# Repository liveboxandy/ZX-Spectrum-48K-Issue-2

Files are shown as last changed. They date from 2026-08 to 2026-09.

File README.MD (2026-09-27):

This is a Kicad 10 project for an issue 2 16/48K ZX spectrum.

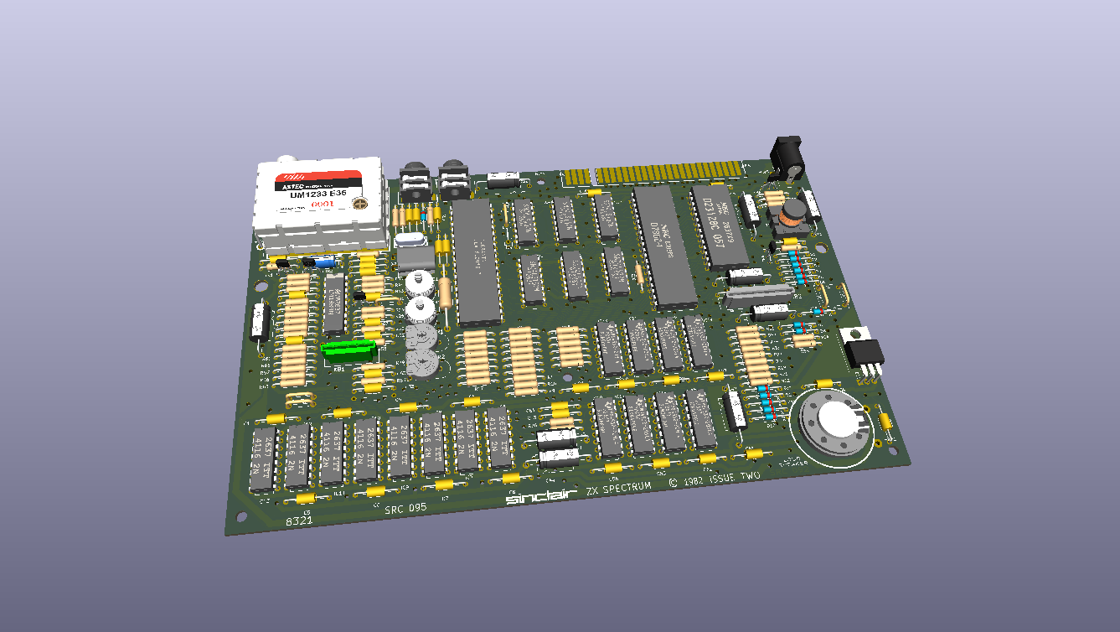
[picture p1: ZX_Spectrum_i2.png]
Assembled PCB


It was only done in order to produce an interactive bom (ibom.html) in the bom folder to aid in the debugging of faulty Speccies.

Although the gerbers appear to be correct to the original PCB I would not use them to get a PCB manufactured without a lot of checking.

It was created by overlaying pictures of a raw Issue 2 PCB, topside and bottomside and then creating the pcb layout from those and a readily available schematic.

Where there are differences the pictures took priority for routing and connections.

Where possible the Sinclair routing has been followed, including all the ground planes. 

Various mods have been released and the following have been applied to the pcb and schematic layout,

D14 replaced by C67 (100pF)                                         - Machine Code fix

R24 changed from 3K3 to (1K)                                        - Machine Code fix

R27 changed from 680R to (470R)                                     - Machine Code fix

R73 added between IC1/32 and +5V (1K)				    - Machine Code fix

C51 in layout between NMI and GND is not fitted, value unknown      - Not fitted

R60 changed from 100R to (270R)                                     - PSU Fix

R48 changed from 4K7 to (2K2)                                       - Colour quality

R49 changed from 18K to (8K2)                                       - Colour quality

R50 changed from 8K2 to (4K7)                                       - Colour Quality

R72 changed from 18K/47K to (10K)                                   - Colour quality

C65 changed from 100uF to (22uF) and positive identified correctly. - Colour quality

The following components do not have positions on the PCB and have to be fitted across other components,

TR6 ZTX313 added to schematic, but not in PCB layout. Base-IC2/30(A0), Collector-IC2/11(+5V), Emitter-IC1/33(IOREQ)

C74 47uF added to schematic but not in PCB layout. +ve TR5E/C34+, -ve TR5B(R58Left) - PSU Fix

ULA 5C112 requires the following,

R47 220R

R49 8K2

R56 220R

R63 220R

ULA 6C001 requires the following

R47 1K

R49 10K

R56 470R

R63 470R

According to the Service Guides, IC25/26 74LS157 should NOT be of NatSemi make.

Updated PCB length & Width along with hole positions. I still wouldn't get a PCB made from these gerbers.
Also included stp files in the /STP folder along with a 3D model of a fully asembled PCB.

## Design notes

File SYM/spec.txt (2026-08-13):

(kicad_symbol_lib
	(generator "kicad_symbol_editor")
	(symbol "23C128"
		(symbol "23C128_1_1"
	(symbol "4116"
		(symbol "4116_1_1"
	(symbol "4532"
		(symbol "4532_1_1"
	(symbol "74LS157"
		(symbol "74LS157_1_0"
		(symbol "74LS157_1_1"
	(symbol "74LS157-IC25-IC26"
		(symbol "74LS157-IC25-IC26_1_0"
		(symbol "74LS157-IC25-IC26_1_1"
	(symbol "BFC280831409"
		(symbol "BFC280831409_1_1"
	(symbol "CONFIG"
		(symbol "CONFIG_0_1"
		(symbol "CONFIG_1_1"
	(symbol "LM1889"
		(symbol "LM1889_1_1"
	(symbol "MODULATOR"
		(symbol "MODULATOR_0_1"
		(symbol "MODULATOR_1_1"
	(symbol "RAM_TYPE"
		(symbol "RAM_TYPE_1_1"
	(symbol "ULA"
		(symbol "ULA_1_1"
	(symbol "Z80CPU"
		(symbol "Z80CPU_0_1"
		(symbol "Z80CPU_1_1"

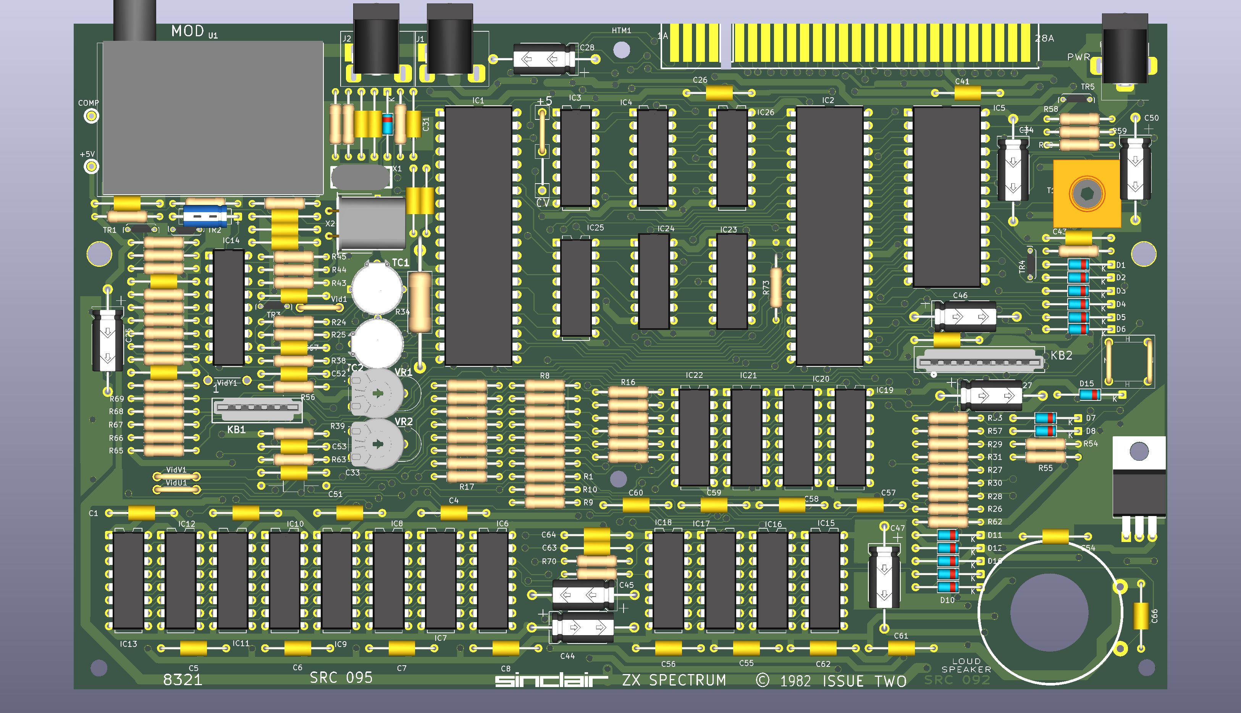
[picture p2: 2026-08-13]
ZX_Spectrum_i2-populated.png

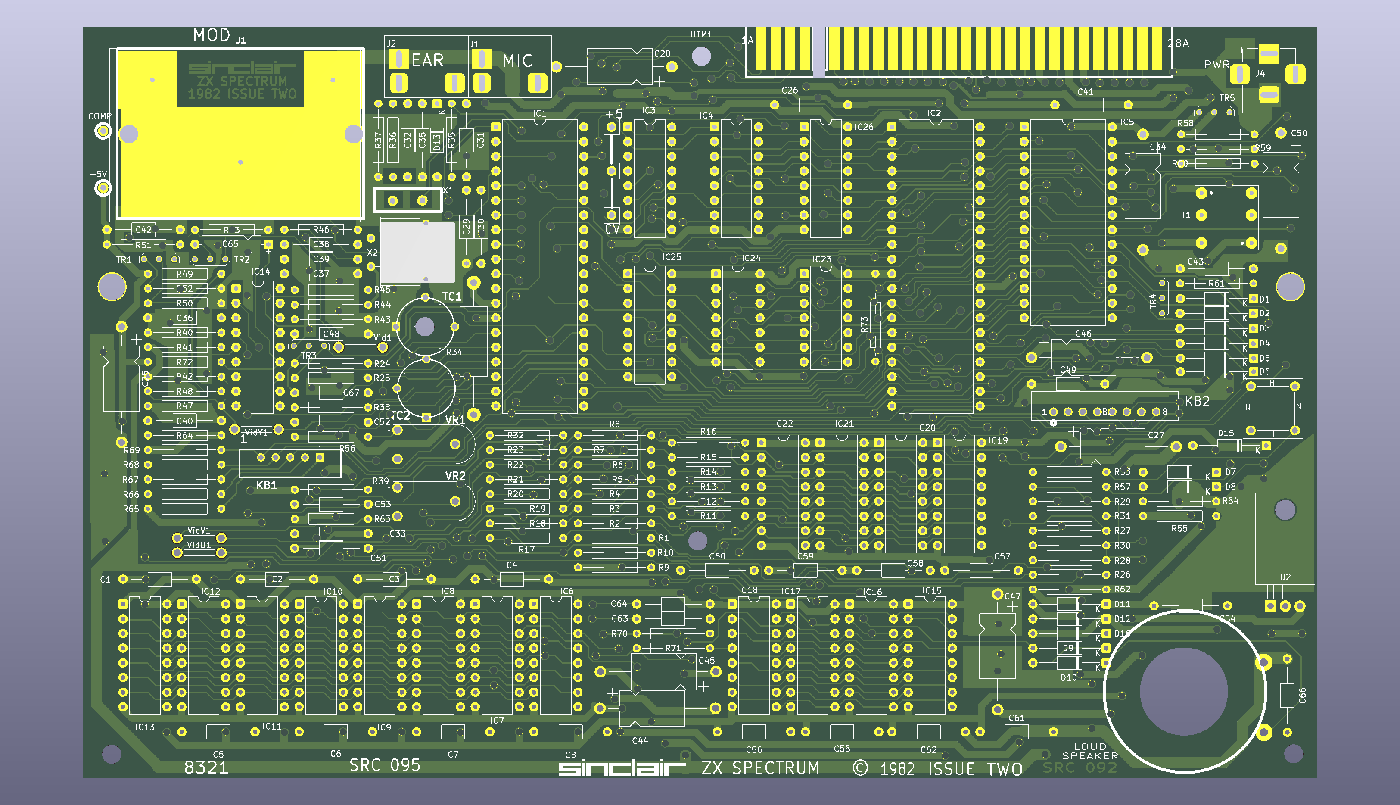
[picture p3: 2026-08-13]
ZX_Spectrum_i2-nonpopulated.png

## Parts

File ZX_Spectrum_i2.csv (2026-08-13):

Source: | E:\Kicad\ZX Spectrum Issue2\ZX_Spectrum_i2.kicad_sch
Date: | 2026-08-13T17:03:00
Tool: | Eeschema 10.0.4
Generator: | C:\Program Files\KiCad\7.0\bin\scripting\plugins/bom_csv_grouped_by_value_with_fp.py
Component Count: | 193
Ref | Qnty | Value | Cmp name | Footprint | Description | Vendor | DNP
C1, C2, C3, C4, C5, C6, C7, C8, C26, C29, C30, C33, C36, C40, C41, C42, C48, C49, C55, C56, C57, C58, C59, C60, C61, C62, C66 | 27 | 47nF | C_Small | MOD:C_Axial_L7.8mm_D2.4mm_P12.70mm_Horizontal | Unpolarized capacitor, small symbol
C25, C28, C47, C50 | 4 | 22uF | C_Polarized_Small | MOD:CP_Axial_L15.6mm_D6.0mm_P20.00mm_Horizontal | Polarized capacitor, small symbol
C27 | 1 | 1uF | C_Polarized_Small | MOD:CP_Axial_L15.6mm_D6.0mm_P20.00mm_Horizontal | Polarized capacitor, small symbol
C31, C32, C43 | 3 | 100nF | C_Small | MOD:C_Axial_L7.8mm_D2.4mm_P12.70mm_Horizontal | Unpolarized capacitor, small symbol
C34 | 1 | 22uF | C_Polarized_Small | MOD:CP_Axial_L11.0mm_D6.0mm_P20.32mm_Horizontal | Polarized capacitor, small symbol
C35, C39 | 2 | 10nF | C_Small | MOD:C_Axial_L7.8mm_D2.4mm_P12.70mm_Horizontal | Unpolarized capacitor, small symbol
C37, C38 | 2 | 33pF | C_Small | MOD:C_Axial_L7.8mm_D2.4mm_P12.70mm_Horizontal | Unpolarized capacitor, small symbol
C44, C45 | 2 | 100uF | C_Polarized_Small | MOD:CP_Axial_L15.6mm_D6.0mm_P20.00mm_Horizontal | Polarized capacitor, small symbol
C46 | 1 | 1uF | C_Polarized_Small | MOD:CP_Axial_L11.0mm_D6.0mm_P20.32mm_Horizontal | Polarized capacitor, small symbol
C52, C53, C64, C67 | 4 | 100pF | C | MOD:C_Axial_L7.8mm_D2.4mm_P12.70mm_Horizontal | Unpolarized capacitor
C54 | 1 | 470pF | C_Small | MOD:C_Axial_L7.8mm_D2.4mm_P12.70mm_Horizontal | Unpolarized capacitor, small symbol
C63 | 1 | 47pF | C_Small | MOD:C_Axial_L7.8mm_D2.4mm_P12.70mm_Horizontal | Unpolarized capacitor, small symbol
C65 | 1 | 22uF | C_Polarized_Small | MOD:CP_Axial_L10.0mm_D2.8mm_P12.70mm_Horizontal | Polarized capacitor, small symbol
C74 | 1 | 47uF | C_Polarized_Small | MOD:CP_Axial_L11.0mm_D6.0mm_P20.32mm_Horizontal | Polarized capacitor, small symbol
D1, D2, D3, D4, D5, D6, D7, D8, D9, D10, D11, D12, D13 | 13 | 1n4148 | D_Small | Diode_THT:D_DO-35_SOD27_P12.70mm_Horizontal | Diode, small symbol
D15 | 1 | BA157 | D_Small | Diode_THT:D_DO-35_SOD27_P12.70mm_Horizontal | Diode, small symbol
D16 | 1 | 5V1 | D_Schottky_Small | Diode_THT:D_DO-35_SOD27_P12.70mm_Horizontal | Schottky diode, small symbol
IC1 | 1 | ULA | ULA | Package_DIP:DIP-40_W15.24mm
IC2 | 1 | Z80 | Z80CPU | Package_DIP:DIP-40_W15.24mm | 8-bit General Purpose Microprocessor, DIP-40
IC3, IC4, IC25, IC26 | 4 | 74LS157 | 74LS157-IC25-IC26 | Package_DIP:DIP-16_W7.62mm | Quad 2 to 1 line Multiplexer
IC5 | 1 | ROM | 23C128 | Package_DIP:DIP-28_W15.24mm | MASKED ROM 128KiBit
IC6, IC7, IC8, IC9, IC10, IC11, IC12, IC13 | 8 | 4116 | 4116 | Package_DIP:DIP-16_W7.62mm | DRAM 16Kbit
IC14 | 1 | LM1889 | LM1889 | Package_DIP:DIP-18_W7.62mm
IC15, IC16, IC17, IC18, IC19, IC20, IC21, IC22 | 8 | 4532 | 4532_1 | Package_DIP:DIP-16_W7.62mm | DRAM 16Kbit
IC23 | 1 | 74LS32 | 74LS32 | Package_DIP:DIP-14_W7.62mm | Quad 2-input OR
IC24 | 1 | 74LS00 | 74LS00 | Package_DIP:DIP-14_W7.62mm | quad 2-input NAND gate
J1 | 1 | MIC | MIC1 | MOD:3.5mm_socket
J2 | 1 | EAR | EAR1 | MOD:3.5mm_socket
J3 | 1 | EDGE CONNECTOR | ZX_48K_EDGE_A_TOP | MOD:ZX_BUS_A_TOP | ZX Spectrum 48K Edge Connector A Top
J4 | 1 | Barrel_Jack | Barrel_Jack_MountingPin | MOD:BarrelJack_Horizontal
KB1 | 1 | KB | 5-520315-5 | MOD:55203155 | 5 Position FFC, FPC Connector Contacts, Vertical - 1 Sided 0.100" (2.54mm) Through Hole
KB2 | 1 | KB | 5-520315-8 | MOD:CONN_5-520315-8_TYC
LNK1 | 1 | ~ | RAM_TYPE | MOD:WireLink2
LNK2 | 1 | ~ | CONFIG | MOD:ROM_WireLink
LS1 | 1 | Speaker | Speaker | MOD:Speaker | Speaker
R1, R2, R3, R4, R5, R6, R7, R8, R27 | 9 | 470R | R_Small | MOD:R_Axial_L7.8mm_D2.4mm_P12.7mm_Horizontal | Resistor, small symbol
R9, R10, R11, R12, R13, R14, R15, R16, R49 | 9 | 8K2 | R_Small | MOD:R_Axial_L7.8mm_D2.4mm_P12.7mm_Horizontal | Resistor, small symbol
R17, R18, R19, R20, R21, R22, R23, R32, R57 | 9 | 330R | R_Small | MOD:R_Axial_L7.8mm_D2.4mm_P12.7mm_Horizontal | Resistor, small symbol
R24 | 1 | 1K0 | R_Small | MOD:R_Axial_L7.8mm_D2.4mm_P12.7mm_Horizontal | Resistor, small symbol
R25 | 1 | 180R | R_Small | MOD:R_Axial_L7.8mm_D2.4mm_P12.7mm_Horizontal | Resistor, small symbol
R26, R33, R36 | 3 | 680R | R_Small | MOD:R_Axial_L7.8mm_D2.4mm_P12.7mm_Horizontal | Resistor, small symbol
R28, R35, R65, R66, R67, R68, R69, R72 | 8 | 10K | R_Small | MOD:R_Axial_L7.8mm_D2.4mm_P12.7mm_Horizontal | Resistor, small symbol
R29, R41 | 2 | 1K5 | R_Small | MOD:R_Axial_L7.8mm_D2.4mm_P12.7mm_Horizontal | Resistor, small symbol
R30, R37, R40, R42, R45, R46 | 6 | 1K | R_Small | MOD:R_Axial_L7.8mm_D2.4mm_P12.7mm_Horizontal | Resistor, small symbol
R31 | 1 | 220K | R_Small | MOD:R_Axial_L7.8mm_D2.4mm_P12.7mm_Horizontal | Resistor, small symbol
R34 | 1 | 15R | R_Small | MOD:R34-11.94-4.5-22.86 | Resistor, small symbol
R38, R39 | 2 | 3K3 | R_Small | MOD:R_Axial_L7.8mm_D2.4mm_P12.7mm_Horizontal | Resistor, small symbol
R43 | 1 | 3K 2% | R_Small | MOD:R_Axial_L7.8mm_D2.4mm_P12.7mm_Horizontal | Resistor, small symbol
R44 | 1 | 5K1 2% | R_Small | MOD:R_Axial_L7.8mm_D2.4mm_P12.7mm_Horizontal | Resistor, small symbol
R47, R56, R63, R70, R71 | 5 | 220R | R_Small | MOD:R_Axial_L7.8mm_D2.4mm_P12.7mm_Horizontal | Resistor, small symbol
R48, R51, R52 | 3 | 2K2 | R_Small | MOD:R_Axial_L7.8mm_D2.4mm_P12.7mm_Horizontal | Resistor, small symbol
R50 | 1 | 4K7 | R_Small | MOD:R_Axial_L7.8mm_D2.4mm_P12.7mm_Horizontal | Resistor, small symbol
R53 | 1 | 390R | R_Small | MOD:R_Axial_L7.8mm_D2.4mm_P12.7mm_Horizontal | Resistor, small symbol
R54 | 1 | 100K | R_Small | MOD:R_Axial_L7.8mm_D2.4mm_P12.7mm_Horizontal | Resistor, small symbol
R55 | 1 | 56R | R_Small | MOD:R_Axial_L7.8mm_D2.4mm_P12.7mm_Horizontal | Resistor, small symbol
R58 | 1 | 1K 2% | R_Small | MOD:R_Axial_L7.8mm_D2.4mm_P12.7mm_Horizontal | Resistor, small symbol
R59 | 1 | 1K8 2% | R_Small | MOD:R_Axial_L7.8mm_D2.4mm_P12.7mm_Horizontal | Resistor, small symbol
R60 | 1 | 270R | R_Small | MOD:R_Axial_L7.8mm_D2.4mm_P12.7mm_Horizontal | Resistor, small symbol
R61, R62, R64 | 3 | 15R | R_Small | MOD:R_Axial_L7.8mm_D2.4mm_P12.7mm_Horizontal | Resistor, small symbol
R73 | 1 | 1K0 | R_Small | MOD:R_Axial_L7.8mm_D2.4mm_P15.20mm_Horizontal | Resistor, small symbol
T1 | 1 | COIL 13/39 | Transformer_1P_1S | MOD:Choke | Transformer, single primary, single secondary
TC1, TC2 | 2 | NS | C_Trim_1 | MOD:TrimmerCap | Trimmable capacitor
TR1, TR2, TR3, TR6 | 4 | ZTX313 | ZTX313 | MOD:TO-92Flat
TR4 | 1 | ZTX650 | Q_NPN_CBE | MOD:TO-92Flat | NPN transistor, collector/base/emitter
TR5 | 1 | ZTX213 | ZTX213 | MOD:TO-92Flat
U1 | 1 | MODULATOR | MODULATOR | MOD:Modulator
U2 | 1 | L7805 | L7805 | Package_TO_SOT_THT:TO-220-3_Horizontal_TabDown | Positive 1.5A 35V Linear Regulator, Fixed Output 5V, TO-220/TO-263/TO-252
Vid1 | 1 | Conn_01x02 | WireLink_7.62mm | MOD:Wire_Link_7.62mm
VidU1 | 1 | Conn_01x02 | WireLink_7.62mm | MOD:Wire_Link_7.62mm
VidV1 | 1 | Conn_01x02 | WireLink_7.62mm | MOD:Wire_Link_7.62mm
VidY1 | 1 | Conn_01x02 | WireLink_7.62mm | MOD:Wire_Link_7.62mm
VR1, VR2 | 2 | 2K2 | R_Potentiometer_Small | MOD:409HS1K | Potentiometer
X1 | 1 | 14MHz | Crystal_Small | MOD:X1 | Two pin crystal, small symbol
X2 | 1 | 4.433619MHz | Crystal_GND3_Small | MOD:Crystal_HC18-U_Horizontal_1EP_style2 | Three pin crystal, GND on pin 3, small symbol

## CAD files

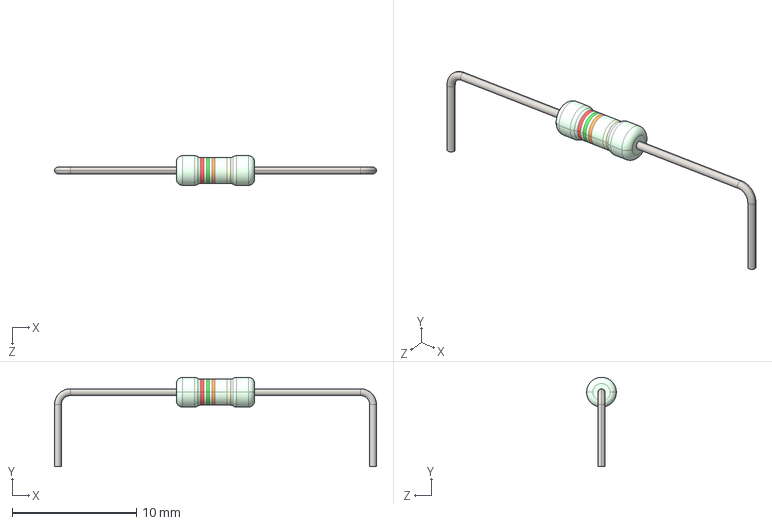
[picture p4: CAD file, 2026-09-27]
STP/Resistor-0207-6.3x2.4x25.40.STEP
26.0 x 7.20 x 2.40 mm

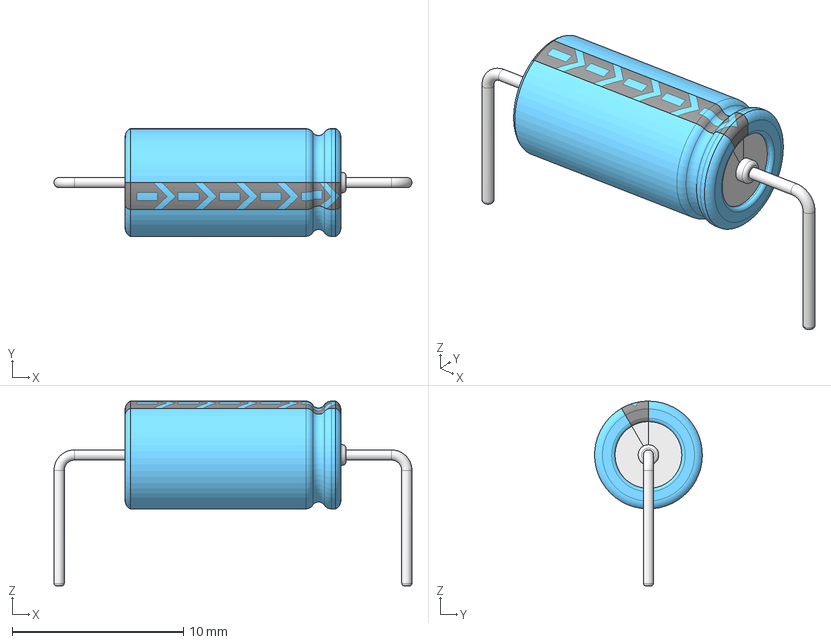
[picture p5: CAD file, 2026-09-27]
STP/Axial Capacitor.step
20.9 x 6.29 x 10.8 mm

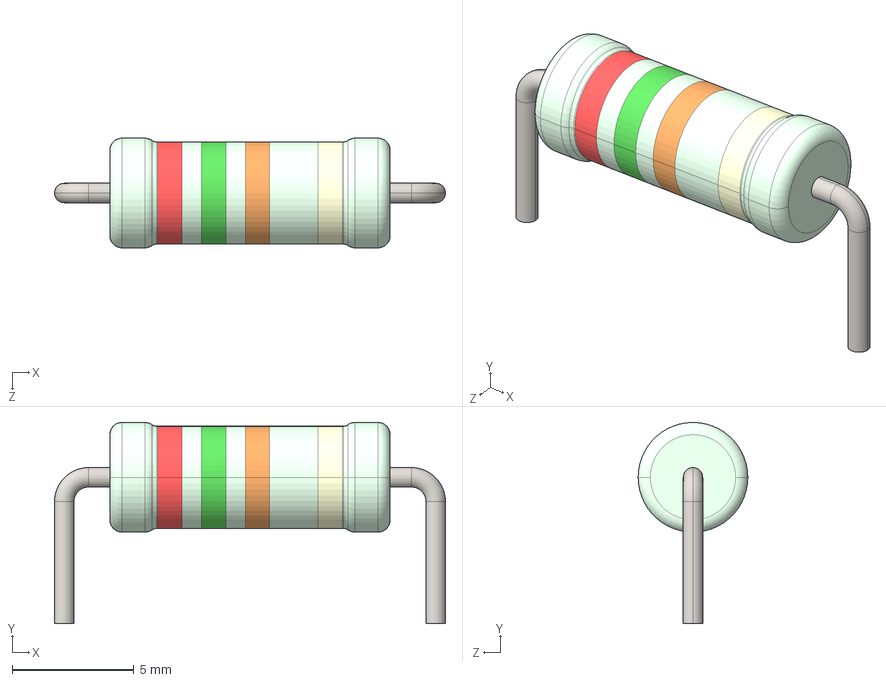
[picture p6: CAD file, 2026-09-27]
STP/Resistor-0414-11.5x4.5x15.24.STEP
16.0 x 8.25 x 4.50 mm

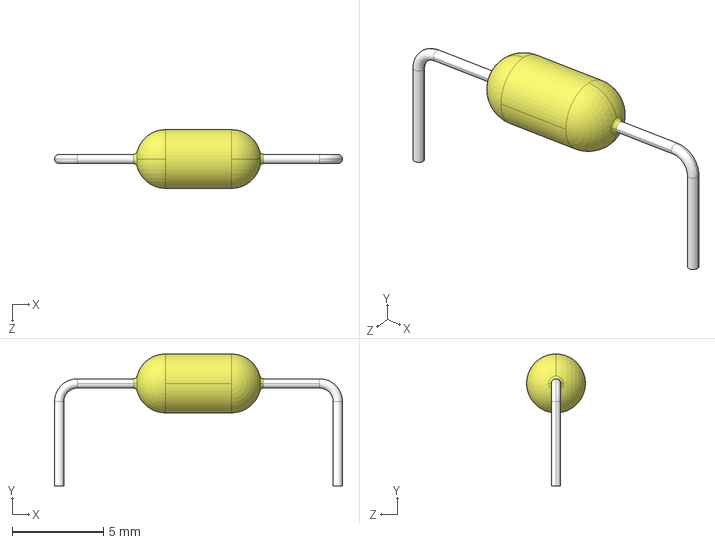
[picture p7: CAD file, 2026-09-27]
STP/Capacitor Ceramic No Polarity axial 15.24.STEP
15.8 x 7.22 x 3.22 mm

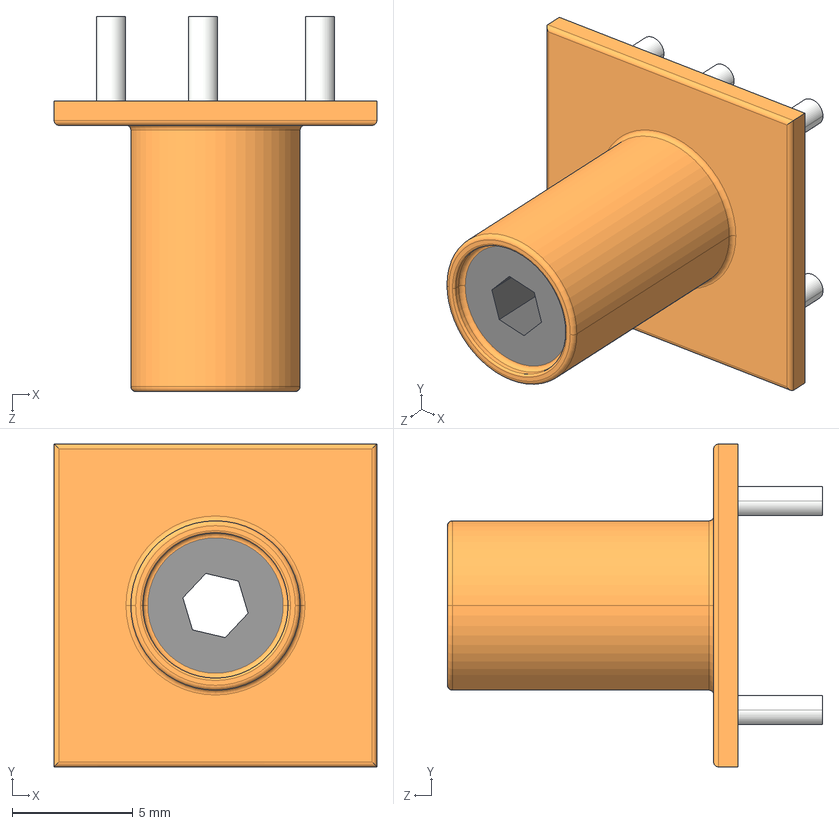
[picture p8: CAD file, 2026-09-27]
STP/13.34x13.34 Bobin.STEP
13.3 x 13.3 x 15.5 mm

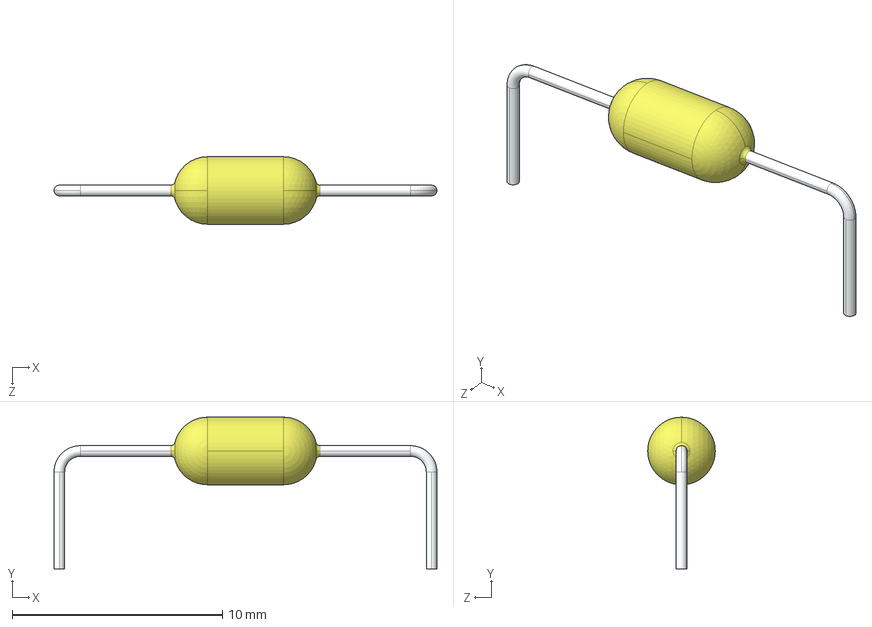
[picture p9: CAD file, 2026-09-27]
STP/Capacitor Ceramic No Polarity axial 17.72.STEP
18.2 x 7.22 x 3.22 mm

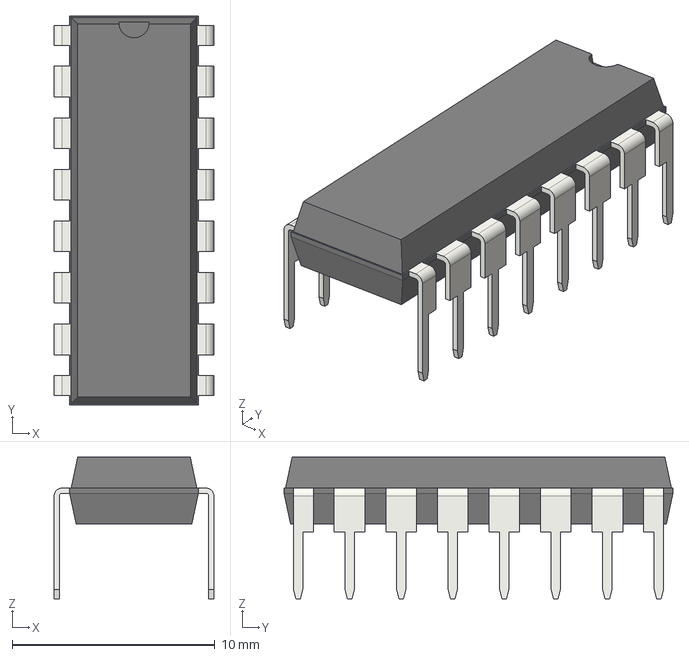
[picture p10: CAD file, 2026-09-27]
STP/DIP-16_W7.62mm.step
7.87 x 19.2 x 6.98 mm

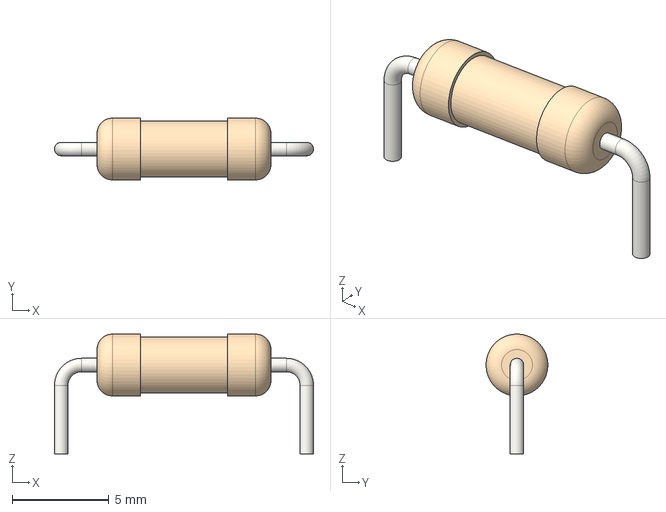
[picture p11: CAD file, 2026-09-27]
STP/R_Axial_DIN0309_L9.0mm_D3.2mm_P12.70mm_Horizontal.step
13.4 x 3.20 x 6.20 mm

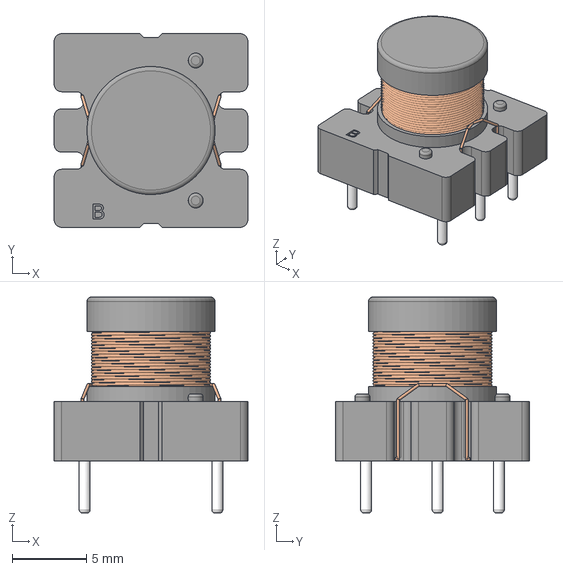
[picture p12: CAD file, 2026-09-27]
STP/COIL_L1.step
13.0 x 13.0 x 14.5 mm

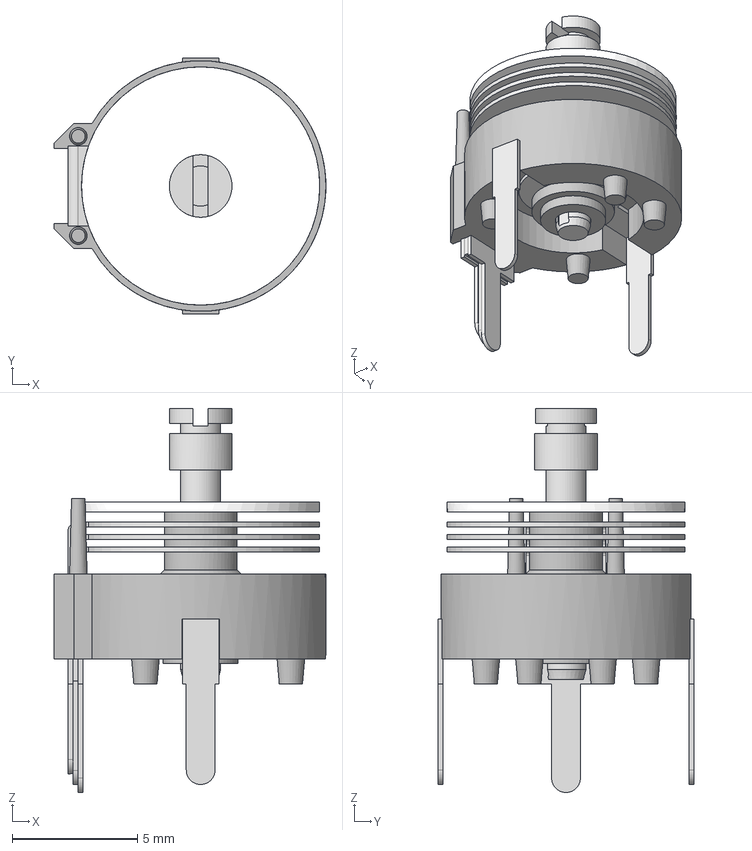
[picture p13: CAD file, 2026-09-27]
STP/Var Cap BFC280831409.stp
10.8 x 10.2 x 15.3 mm

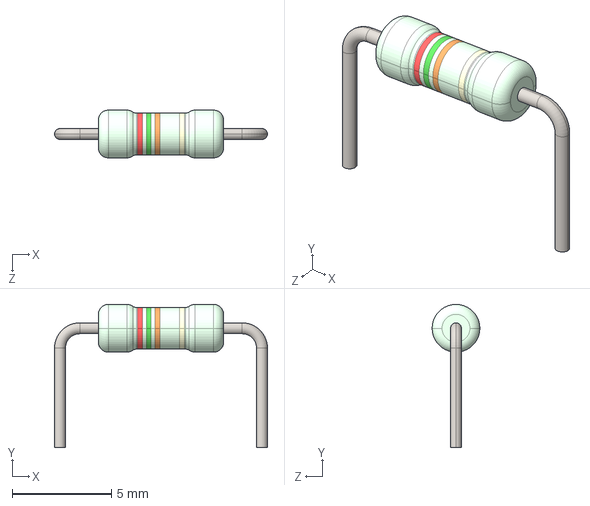
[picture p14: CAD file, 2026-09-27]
STP/Resistor-0207-6.3x2.4x10.16.STEP
10.7 x 7.20 x 2.40 mm

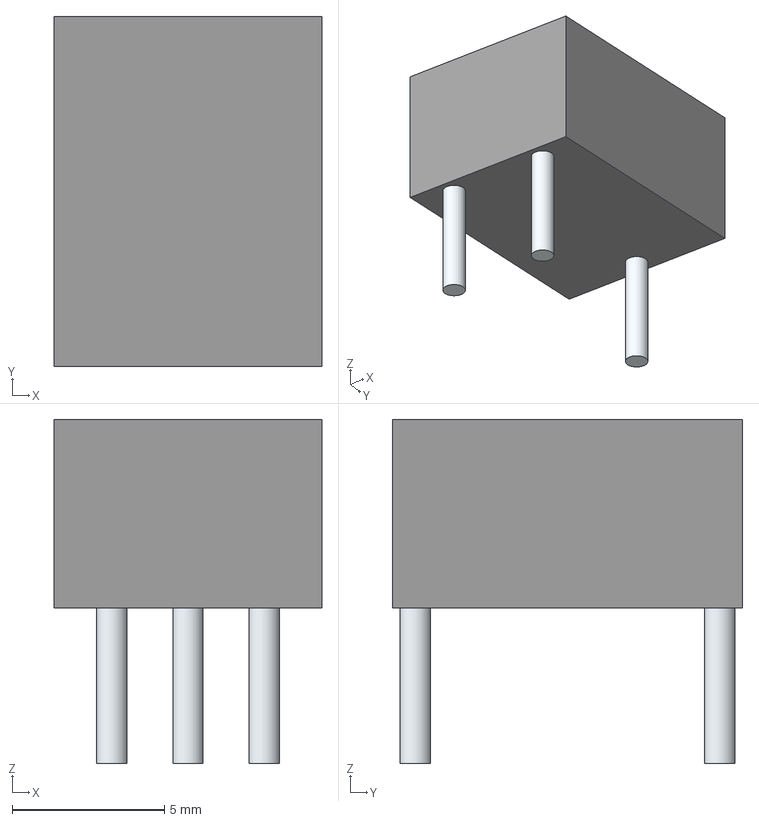
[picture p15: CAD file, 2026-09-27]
STP/409HS-1K.stp
8.80 x 11.5 x 11.3 mm
Leads

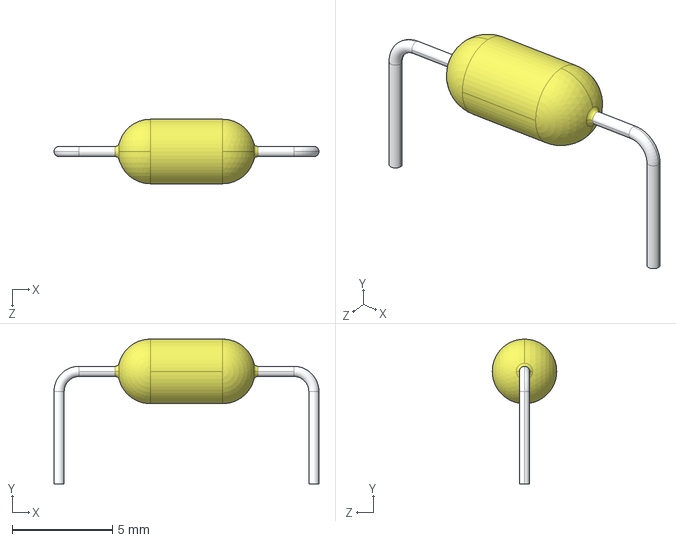
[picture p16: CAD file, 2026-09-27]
STP/Capacitor Ceramic No Polarity axial 12.70.STEP
13.2 x 7.22 x 3.22 mm

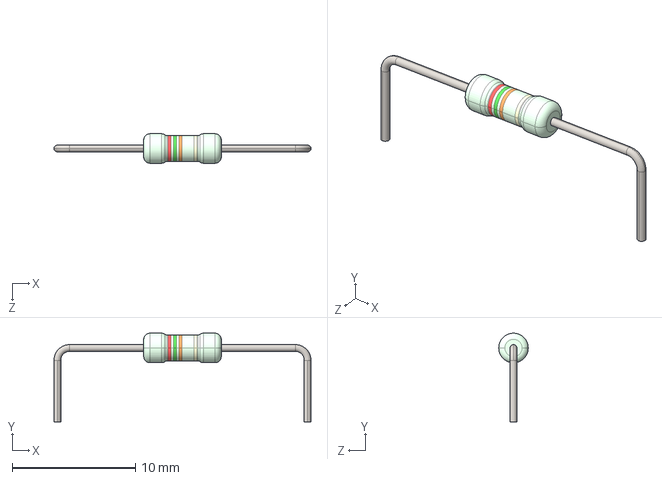
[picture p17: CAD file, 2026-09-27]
STP/Resistor-0207-6.3x2.4x20.32.STEP
20.9 x 7.20 x 2.40 mm

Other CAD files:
STP/TI_TMS4532.step
STP/DO-41-5.10x2.60x15.24.STEP
STP/MOT_SN74LS00N.step
STP/MOT_SN74LS157N.step
STP/22-02-3053.stp
STP/22-02-3083.stp
STP/5-520315-5.stp
STP/AUDIO_JACK_3PIN.step
STP/Axial Capacitor Old.step
STP/CMS-1805-24SP.stp
STP/CONN-TH_5P-P2.54_520315-5.step
STP/CONN-TH_8P-P2.54_520315-8.step
STP/CONN_5-520315-8_TYC.stp
STP/CP 13x5x0.5x12.70.STEP
STP/CP 13x5x0.5x15.24.STEP
STP/CP 13x5x0.5x17.78.STEP
STP/CP 13x5x0.5x20.32.STEP
STP/CP 13x5x0.5x22.86.STEP
STP/CP 13x5x0.5x25.40.STEP
STP/Capacitor Ceramic No Polarity axial 10.16.STEP
STP/Capacitor Ceramic No Polarity axial 20.32.STEP
STP/Capacitor Ceramic No Polarity axial 22.86.STEP
STP/Capacitor Ceramic No Polarity axial 25.40.STEP
STP/Crystal-HC18-U RA.STEP
STP/Crystal-HC49-U.stp
STP/Crystal-Low.stp
STP/DC Power Connector FC68148_20DC10A_202.1mm.STP
STP/DIP-14_W7.62mm.step
STP/DIP-14_W7.62mm_Socket.step
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

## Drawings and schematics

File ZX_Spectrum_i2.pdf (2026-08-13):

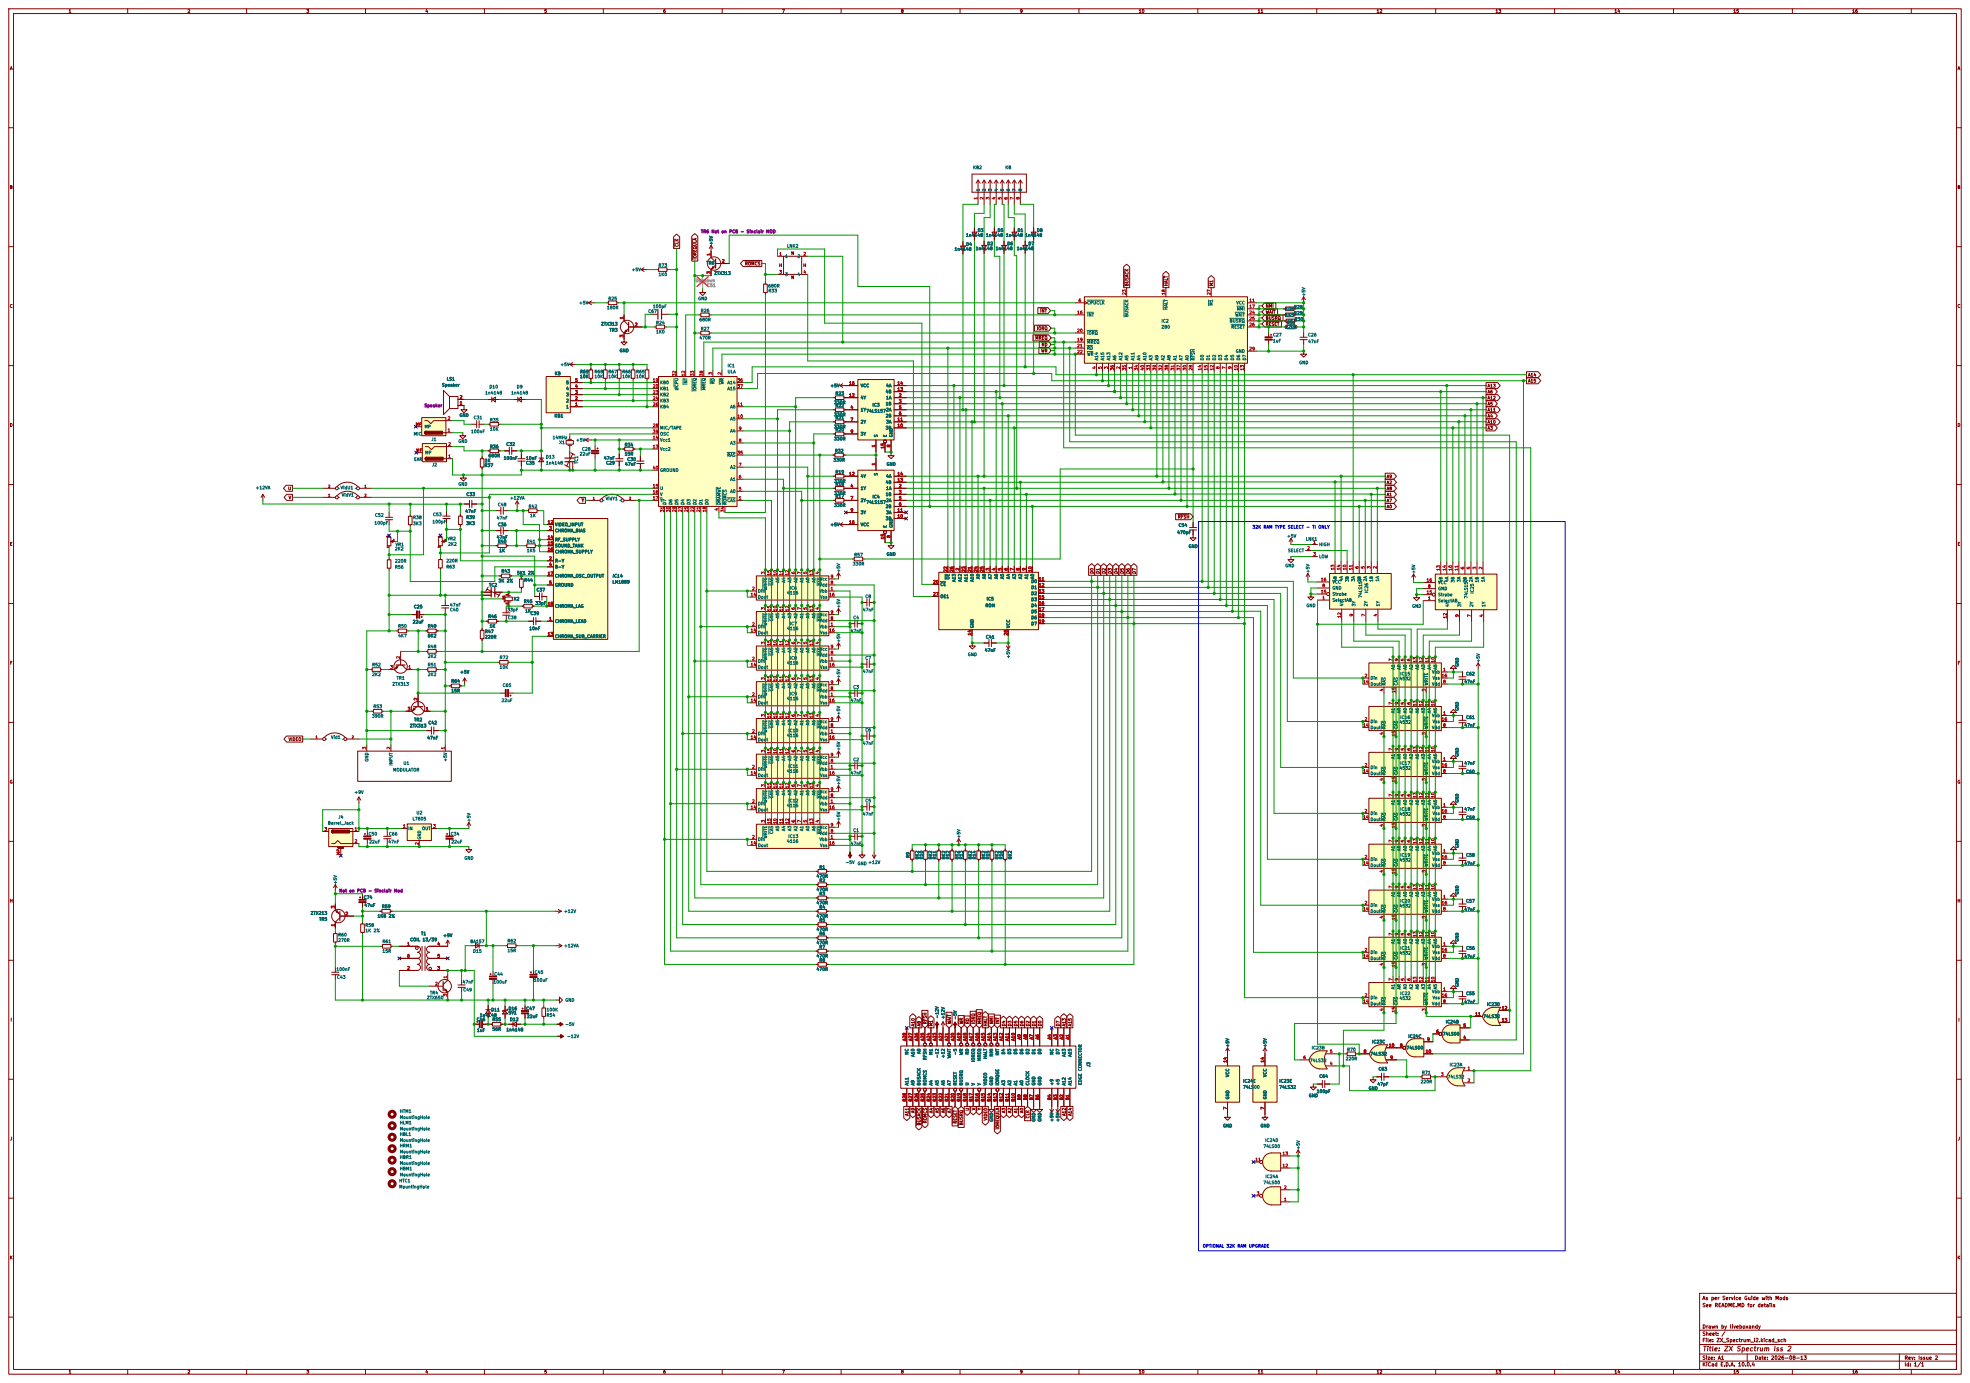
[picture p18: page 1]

TR6 Not on PCB - Sinclair MOD

32K RAM TYPE SELECT - TI ONLY

15 D4
16 D5 16 D5 17 D6 17 D6

CAS 15 IC18 | Vdd A5 10 A4 11 A3 12 A6 13 Dout 14 | 8 AR 9

47uF Not on PCB - Sinclair Mod R58

As per Service Guide with Mods
See README.MD for details

Drawn by liveboxandy
Sheet: /
File: ZX_Spectrum_i2.kicad_sch
Title: ZX Spectrum Iss 2

Size: A1 | Rev: Issue 2
KiCad E.D.A. 10.0.4 | Id: 1/1

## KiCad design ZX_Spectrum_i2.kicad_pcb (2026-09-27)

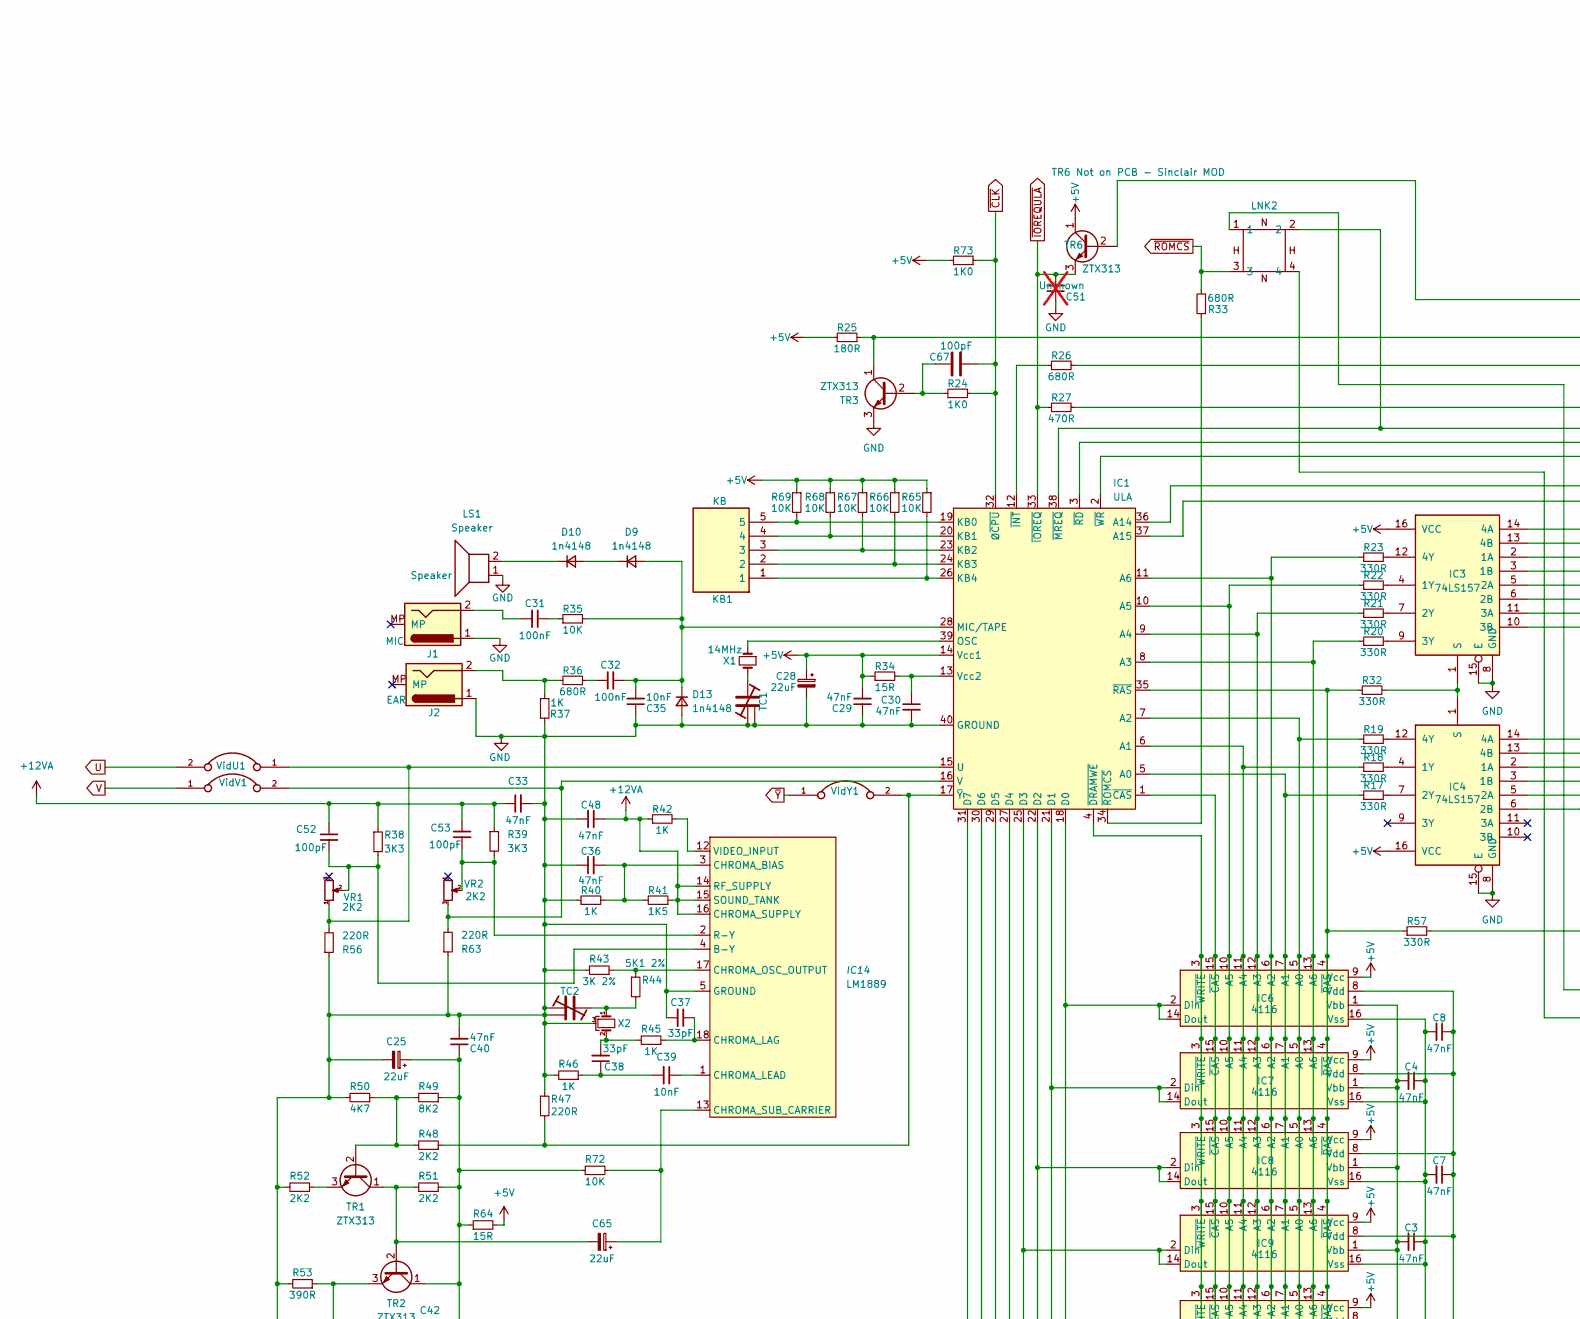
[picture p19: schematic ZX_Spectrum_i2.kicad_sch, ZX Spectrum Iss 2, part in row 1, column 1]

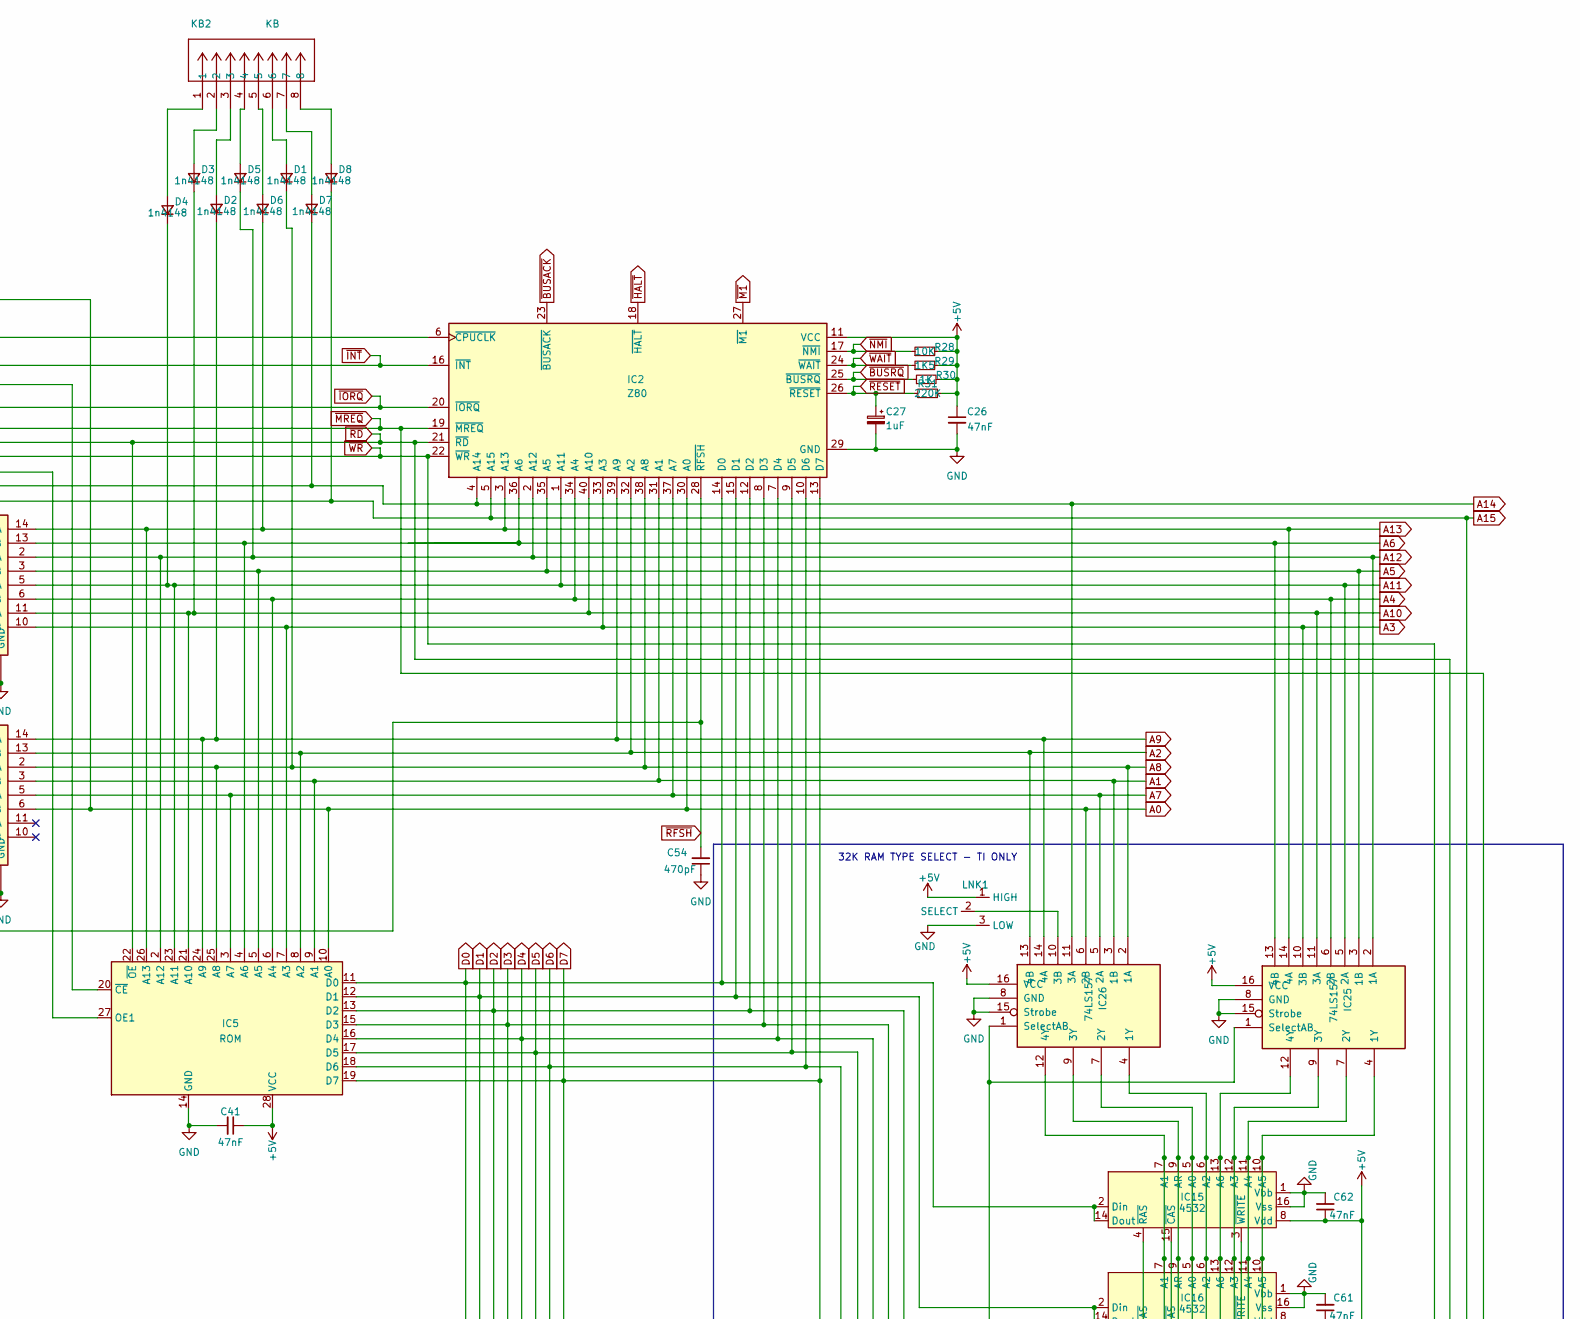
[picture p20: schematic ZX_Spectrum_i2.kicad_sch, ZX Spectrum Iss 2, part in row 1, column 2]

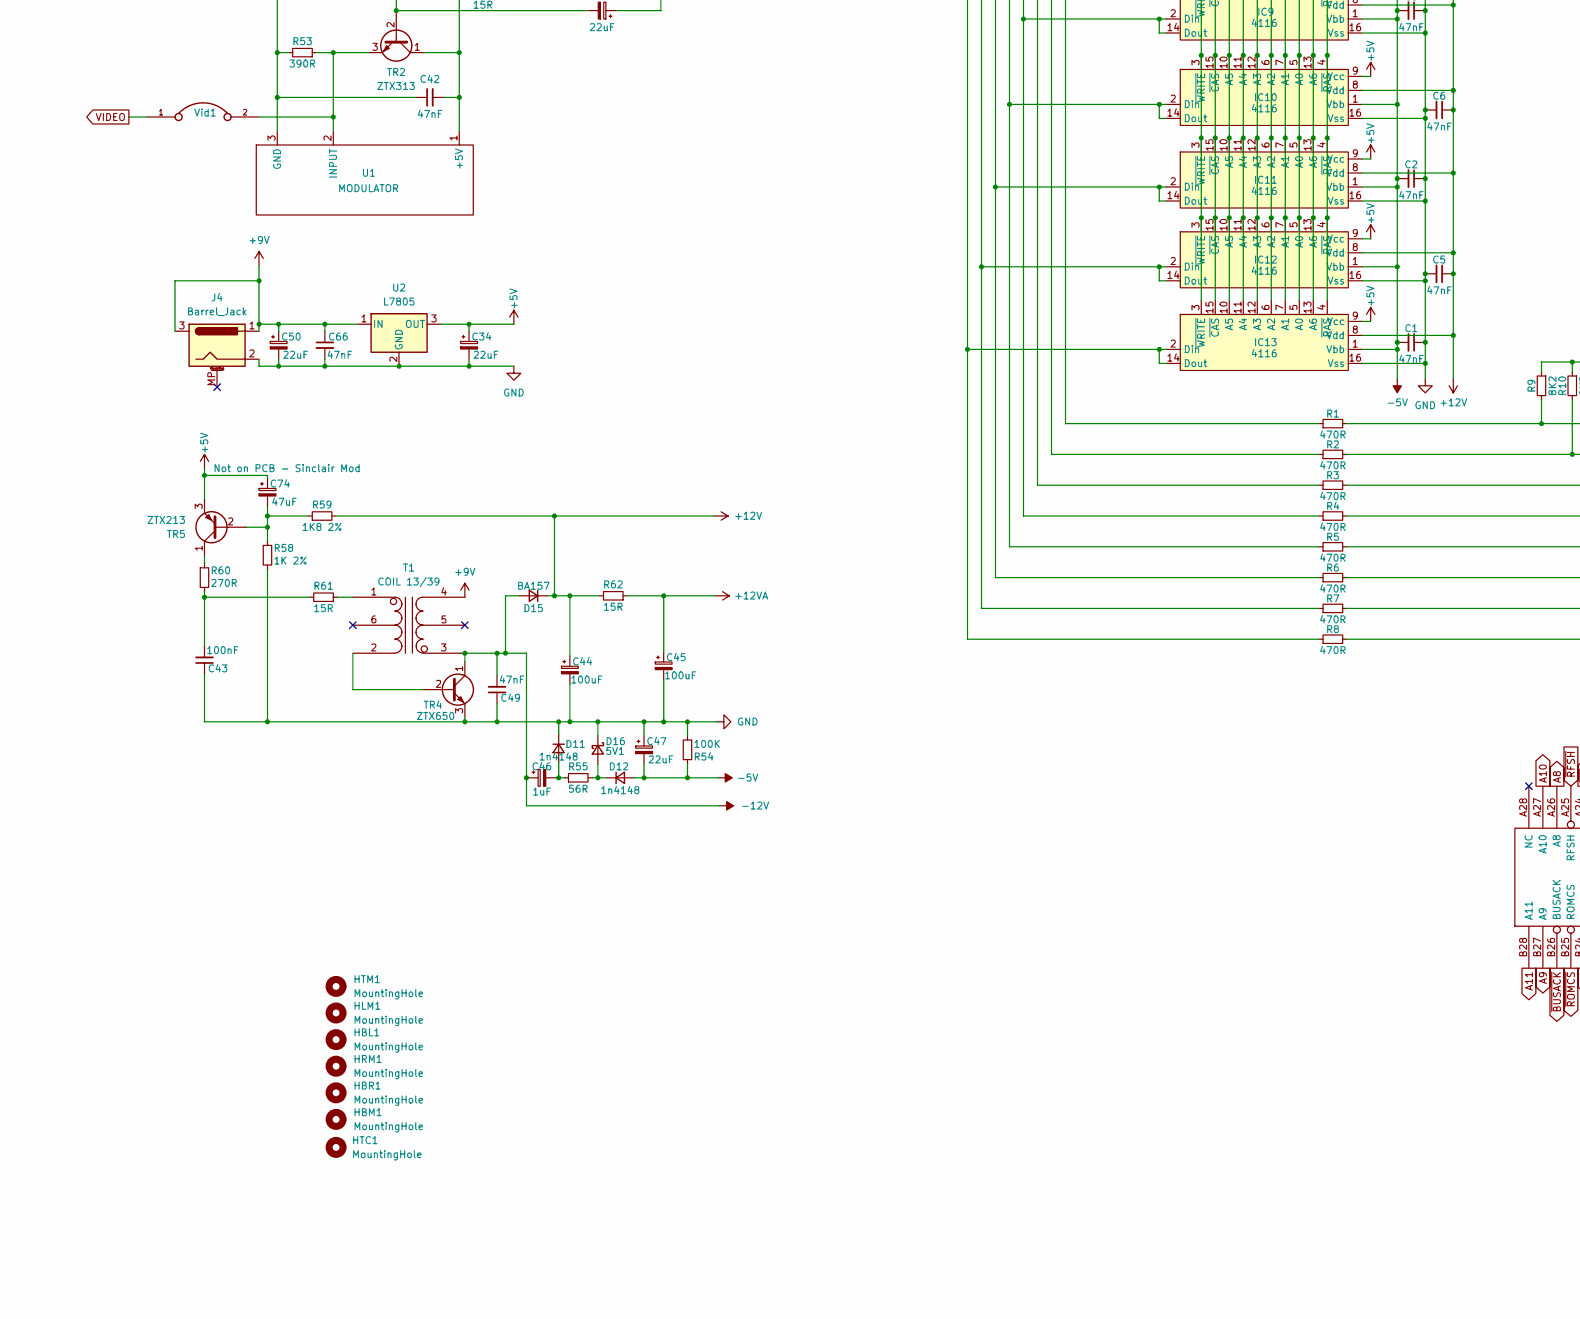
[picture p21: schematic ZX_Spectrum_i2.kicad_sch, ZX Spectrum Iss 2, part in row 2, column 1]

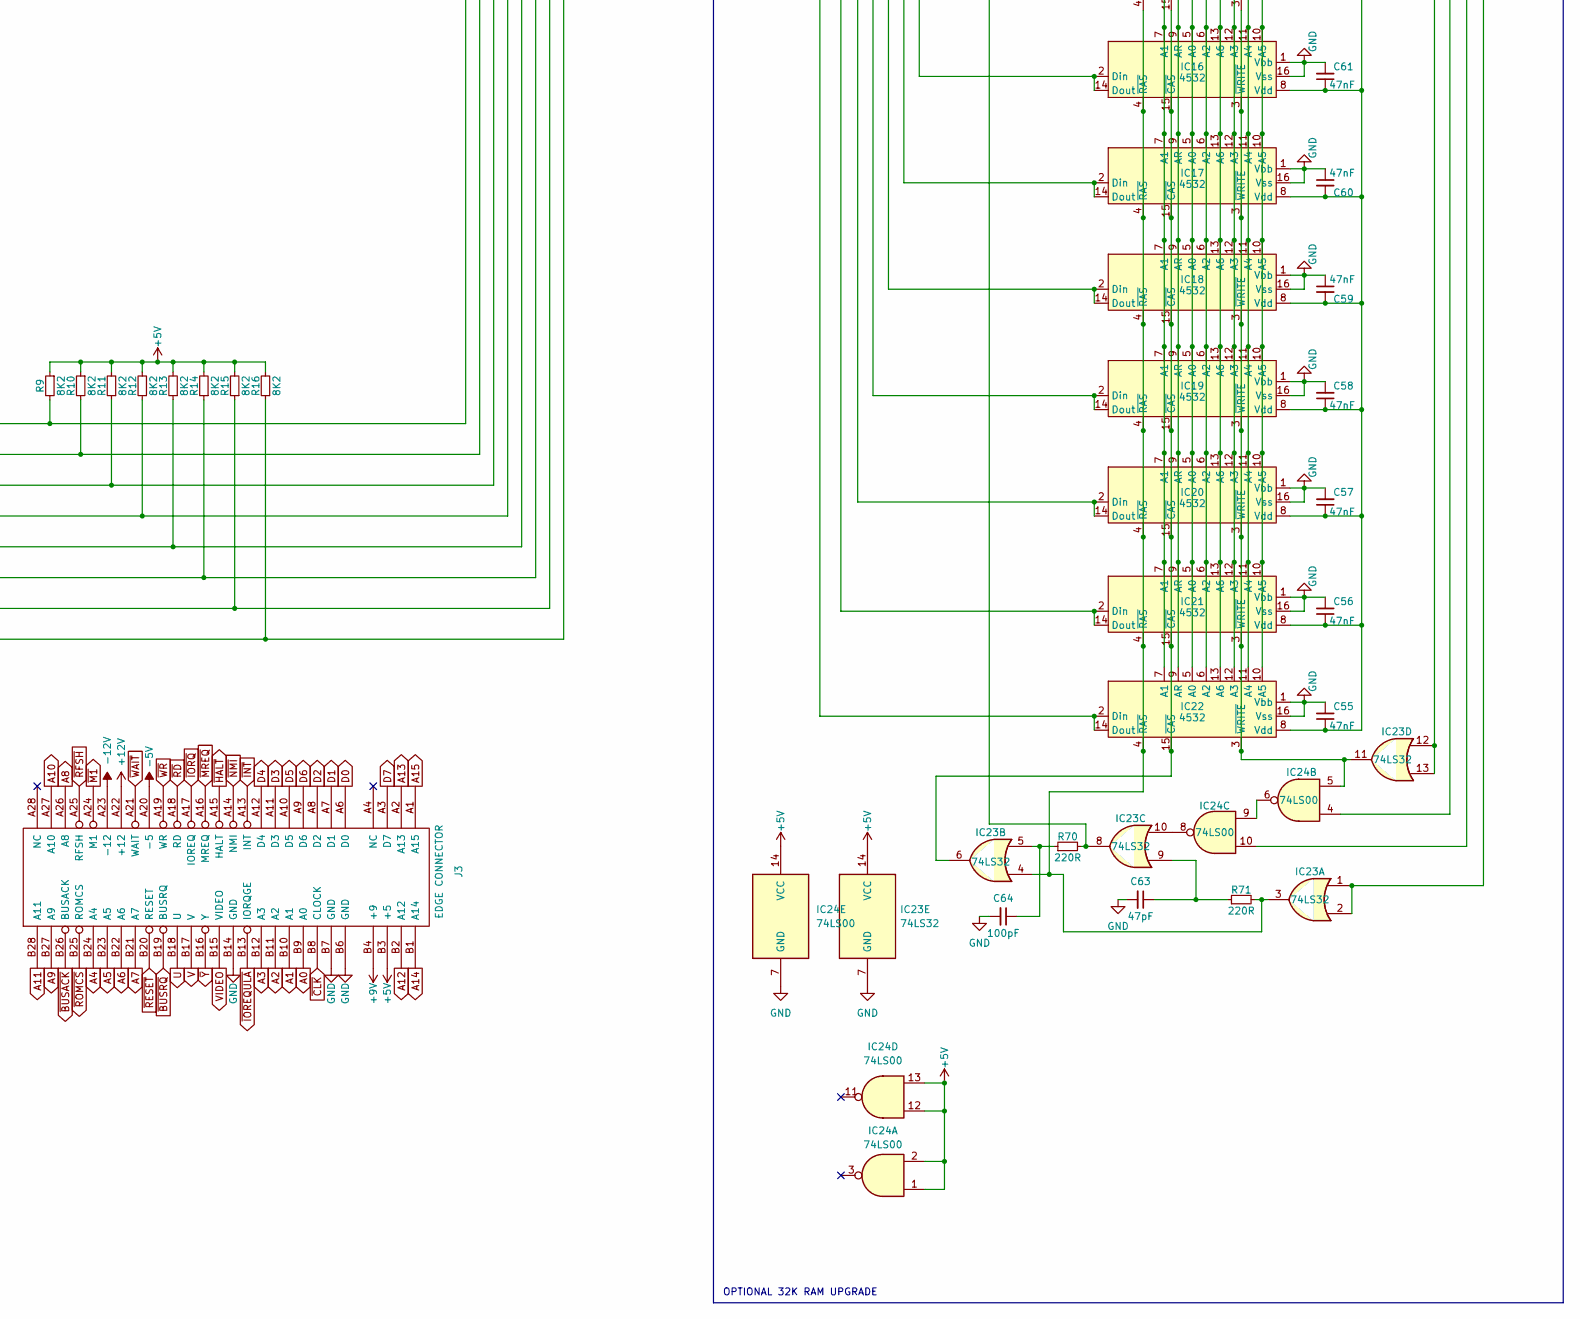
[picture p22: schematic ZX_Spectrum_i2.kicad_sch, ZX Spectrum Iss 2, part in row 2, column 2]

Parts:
C1, C2, C3, C4, C5, C6, C7, C8, C26, C29, C30, C33, C36, C40, C41, C42, C48, C49, C55, C56, C57, C58, C59, C60, C61, C62, C66: 47nF; C_Axial_L7.8mm_D2.4mm_P12.70mm_Horizontal
C25, C28, C47, C50: 22uF; CP_Axial_L15.6mm_D6.0mm_P20.00mm_Horizontal
C27: 1uF; CP_Axial_L15.6mm_D6.0mm_P20.00mm_Horizontal
C31, C32, C43: 100nF; C_Axial_L7.8mm_D2.4mm_P12.70mm_Horizontal
C34: 22uF; CP_Axial_L11.0mm_D6.0mm_P20.32mm_Horizontal
C35, C39: 10nF; C_Axial_L7.8mm_D2.4mm_P12.70mm_Horizontal
C37, C38: 33pF; C_Axial_L7.8mm_D2.4mm_P12.70mm_Horizontal
C44, C45: 100uF; CP_Axial_L15.6mm_D6.0mm_P20.00mm_Horizontal
C46: 1uF; CP_Axial_L11.0mm_D6.0mm_P20.32mm_Horizontal
C51: Unknown; C_Axial_L7.8mm_D2.4mm_P12.70mm_Horizontal; not fitted
C52, C53, C64, C67: 100pF; C_Axial_L7.8mm_D2.4mm_P12.70mm_Horizontal
C54: 470pF; C_Axial_L7.8mm_D2.4mm_P12.70mm_Horizontal
C63: 47pF; C_Axial_L7.8mm_D2.4mm_P12.70mm_Horizontal
C65: 22uF; CP_Axial_L10.0mm_D2.8mm_P12.70mm_Horizontal
C74: 47uF; CP_Axial_L11.0mm_D6.0mm_P20.32mm_Horizontal
D1, D2, D3, D4, D5, D6, D7, D8, D9, D10, D11, D12, D13: 1n4148; D_DO-35_SOD27_P12.70mm_Horizontal
D15: BA157; D_DO-35_SOD27_P12.70mm_Horizontal
D16: 5V1; D_DO-35_SOD27_P12.70mm_Horizontal
HBL1: MountingHole; MountingHole_3.3mm Spectrum
HBM1: MountingHole; MountingHole_3.3mm Spectrum
HBR1: MountingHole; MountingHole_3.3mm Spectrum
HLM1: MountingHole; MountingHole_5mm Spectrum
HRM1: MountingHole; MountingHole_5mm Spectrum
HTC1: MountingHole; MountingHole_3.3mm Spectrum
HTM1: MountingHole; MountingHole_3.3mm Spectrum
IC1: ULA; DIP-40_W15.24mm
IC2: Z80; DIP-40_W15.24mm
IC3, IC4, IC25, IC26: 74LS157; DIP-16_W7.62mm
IC5: ROM; DIP-28_W15.24mm
IC6, IC7, IC8, IC9, IC10, IC11, IC12, IC13: 4116; DIP-16_W7.62mm
IC14: LM1889; DIP-18_W7.62mm
IC15, IC16, IC17, IC18, IC19, IC20, IC21, IC22: 4532; DIP-16_W7.62mm
IC23: 74LS32; DIP-14_W7.62mm
IC24: 74LS00; DIP-14_W7.62mm
J1: MIC; 3.5mm_socket
J2: EAR; 3.5mm_socket
J3: EDGE CONNECTOR; ZX_BUS_A_TOP
J4: Barrel_Jack; BarrelJack_Horizontal
KB1: KB; 55203155
KB2: KB; CONN_5-520315-8_TYC
LNK1: WireLink2
LNK2: ROM_WireLink
LS1: Speaker
R1, R2, R3, R4, R5, R6, R7, R8, R27: 470R; R_Axial_L7.8mm_D2.4mm_P12.7mm_Horizontal
R9, R10, R11, R12, R13, R14, R15, R16, R49: 8K2; R_Axial_L7.8mm_D2.4mm_P12.7mm_Horizontal
R17, R18, R19, R20, R21, R22, R23, R32, R57: 330R; R_Axial_L7.8mm_D2.4mm_P12.7mm_Horizontal
R24: 1K0; R_Axial_L7.8mm_D2.4mm_P12.7mm_Horizontal
R25: 180R; R_Axial_L7.8mm_D2.4mm_P12.7mm_Horizontal
R26, R33, R36: 680R; R_Axial_L7.8mm_D2.4mm_P12.7mm_Horizontal
R28, R35, R65, R66, R67, R68, R69, R72: 10K; R_Axial_L7.8mm_D2.4mm_P12.7mm_Horizontal
R29, R41: 1K5; R_Axial_L7.8mm_D2.4mm_P12.7mm_Horizontal
R30, R37, R40, R42, R45, R46: 1K; R_Axial_L7.8mm_D2.4mm_P12.7mm_Horizontal
R31: 220K; R_Axial_L7.8mm_D2.4mm_P12.7mm_Horizontal
R34: 15R; R34-11.94-4.5-22.86
R38, R39: 3K3; R_Axial_L7.8mm_D2.4mm_P12.7mm_Horizontal
R43: 3K 2%; R_Axial_L7.8mm_D2.4mm_P12.7mm_Horizontal
R44: 5K1 2%; R_Axial_L7.8mm_D2.4mm_P12.7mm_Horizontal
R47, R56, R63, R70, R71: 220R; R_Axial_L7.8mm_D2.4mm_P12.7mm_Horizontal
R48, R51, R52: 2K2; R_Axial_L7.8mm_D2.4mm_P12.7mm_Horizontal
R50: 4K7; R_Axial_L7.8mm_D2.4mm_P12.7mm_Horizontal
R53: 390R; R_Axial_L7.8mm_D2.4mm_P12.7mm_Horizontal
R54: 100K; R_Axial_L7.8mm_D2.4mm_P12.7mm_Horizontal
R55: 56R; R_Axial_L7.8mm_D2.4mm_P12.7mm_Horizontal
R58: 1K 2%; R_Axial_L7.8mm_D2.4mm_P12.7mm_Horizontal
R59: 1K8 2%; R_Axial_L7.8mm_D2.4mm_P12.7mm_Horizontal
R60: 270R; R_Axial_L7.8mm_D2.4mm_P12.7mm_Horizontal
R61, R62, R64: 15R; R_Axial_L7.8mm_D2.4mm_P12.7mm_Horizontal
R73: 1K0; R_Axial_L7.8mm_D2.4mm_P15.20mm_Horizontal
T1: COIL 13/39; Choke
TC1, TC2: NS; TrimmerCap
TR1, TR2, TR3, TR6: ZTX313; TO-92Flat
TR4: ZTX650; TO-92Flat
TR5: ZTX213; TO-92Flat
U1: MODULATOR; Modulator
U2: L7805; TO-220-3_Horizontal_TabDown
VR1, VR2: 2K2; 409HS1K
Vid1: Conn_01x02; Wire_Link_7.62mm
VidU1: Conn_01x02; Wire_Link_7.62mm
VidV1: Conn_01x02; Wire_Link_7.62mm
VidY1: Conn_01x02; Wire_Link_7.62mm
X1: 14MHz; X1
X2: 4.433619MHz; Crystal_HC18-U_Horizontal_1EP_style2

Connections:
+5V: C26.1, C28.1, C29.2, C34.1, C41.1, C55.1, C56.1, C57.1, C58.1, C59.2, C60.2, C61.1, C62.1, C74.1, IC1.14 (Vcc1), IC2.11 (VCC), IC3.16 (VCC), IC4.16 (VCC), IC5.28 (VCC), IC6.9 (Vcc), IC7.9 (Vcc), IC8.9 (Vcc), IC9.9 (Vcc), IC10.9 (Vcc), IC11.9 (Vcc), IC12.9 (Vcc), IC13.9 (Vcc), IC15.8 (Vdd), IC16.8 (Vdd), IC17.8 (Vdd), IC18.8 (Vdd), IC19.8 (Vdd), IC20.8 (Vdd), IC21.8 (Vdd), IC22.8 (Vdd), IC23.14 (VCC), IC24.1, IC24.2, IC24.12, IC24.13, IC24.14 (VCC), IC25.16 (VCC), IC26.16 (VCC), J3.B3 (+5), LNK1.1 (HIGH), R9.1, R10.1, R11.2, R12.2, R13.2, R14.2, R15.2, R16.2, R25.2, R28.2, R29.2, R30.2, R31.2, R34.1, R64.2, R65.1, R66.1, R67.1, R68.1, R69.1, R73.2, TR5.3 (E), TR6.1 (C), U2.3 (OUT)
+9V: C50.1, C66.1, J3.B4 (+9), J4.1, J4.3 (MP2_3), T1.4 (SB), U2.1 (IN)
+12V: C5.1, C6.1, C7.1, C8.1, C44.1, D15.1 (K), IC6.8 (Vdd), IC7.8 (Vdd), IC8.8 (Vdd), IC9.8 (Vdd), IC10.8 (Vdd), IC11.8 (Vdd), IC12.8 (Vdd), IC13.8 (Vdd), J3.A22 (+12), R59.2, R62.2
+12VA: C33.1, C45.1, C48.1, C52.1, C53.1, IC14.14 (RF_SUPPLY), IC14.15 (SOUND_TANK), IC14.16 (CHROMA_SUPPLY), R38.1, R39.1, R41.1, R42.1, R62.1
-5V: C1.2, C2.2, C3.2, C4.2, C47.2, D12.2 (A), IC6.1 (Vbb), IC7.1 (Vbb), IC8.1 (Vbb), IC9.1 (Vbb), IC10.1 (Vbb), IC11.1 (Vbb), IC12.1 (Vbb), IC13.1 (Vbb), J3.A20 (-5), R54.1
-12V: C46.1, C49.2, D15.2 (A), J3.A23 (-12), T1.3 (SA), TR4.1 (C)
A0: IC2.30 (A0), IC4.6 (2B), IC5.10 (A0), IC26.6 (2B), J3.B9 (A0), TR6.2 (B)
A1: IC2.31 (A1), IC4.3 (1B), IC5.9 (A1), IC26.3 (1B), J3.B10 (A1)
A2: IC2.32 (A2), IC4.13 (4B), IC5.8 (A2), IC26.13 (4B), J3.B11 (A2)
A3: IC2.33 (A3), IC3.10 (3B), IC5.7 (A3), IC25.10 (3B), J3.B12 (A3)
A4: IC2.34 (A4), IC3.6 (2B), IC5.6 (A4), IC25.6 (2B), J3.B24 (A4)
A5: IC2.35 (A5), IC3.3 (1B), IC5.5 (A5), IC25.3 (1B), J3.B23 (A5)
A6: IC2.36 (A6), IC3.13 (4B), IC5.4 (A6), IC25.13 (4B), J3.B22 (A6)
A7: IC2.37 (A7), IC4.5 (2A), IC5.3 (A7), IC26.5 (2A), J3.B21 (A7)
A8: D1.1 (K), IC2.38 (A8), IC4.2 (1A), IC5.25 (A8), IC26.2 (1A), J3.A26 (A8)
A9: D2.1 (K), IC2.39 (A9), IC4.14 (4A), IC5.24 (A9), IC26.14 (4A), J3.B27 (A9)
A10: D3.1 (K), IC2.40 (A10), IC3.11 (3A), IC5.21 (A10), IC25.11 (3A), J3.A27 (A10)
A11: D4.1 (K), IC2.1 (A11), IC3.5 (2A), IC5.23 (A11), IC25.5 (2A), J3.B28 (A11)
A12: D5.1 (K), IC2.2 (A12), IC3.2 (1A), IC5.2 (A12), IC25.2 (1A), J3.B2 (A12)
A13: D6.1 (K), IC2.3 (A13), IC3.14 (4A), IC5.26 (A13), IC25.14 (4A), J3.A2 (A13)
A14: D7.1 (K), IC1.36 (A14), IC2.4 (A14), IC26.11 (3A), J3.B1 (A14)
A15: D8.1 (K), IC1.37 (A15), IC2.5 (A15), IC24.10, J3.A1 (A15)
D0: IC2.14 (D0), IC5.11 (D0), IC15.2 (Din), IC15.14 (Dout), J3.A6 (D0), R1.2, R9.2
D1: IC2.15 (D1), IC5.12 (D1), IC16.2 (Din), IC16.14 (Dout), J3.A7 (D1), R2.2, R10.2
D2: IC2.12 (D2), IC5.13 (D2), IC17.2 (Din), IC17.14 (Dout), J3.A8 (D2), R3.2, R11.1
D3: IC2.8 (D3), IC5.15 (D3), IC18.2 (Din), IC18.14 (Dout), J3.A11 (D3), R4.2, R12.1
D4: IC2.7 (D4), IC5.16 (D4), IC19.2 (Din), IC19.14 (Dout), J3.A12 (D4), R5.2, R13.1
D5: IC2.9 (D5), IC5.17 (D5), IC20.2 (Din), IC20.14 (Dout), J3.A10 (D5), R6.2, R14.1
D6: IC2.10 (D6), IC5.18 (D6), IC21.2 (Din), IC21.14 (Dout), J3.A9 (D6), R7.2, R15.1
D7: IC2.13 (D7), IC5.19 (D7), IC22.2 (Din), IC22.14 (Dout), J3.A3 (D7), R8.2, R16.1
GND: C1.1, C2.1, C3.1, C4.1, C5.2, C6.2, C7.2, C8.2, C25.2, C26.2, C27.2, C28.2, C29.1, C30.2, C33.2, C34.2, C35.1, C36.1, C37.2, C40.2, C41.2, C42.1, C43.1, C44.2, C45.2, C47.1, C48.2, C49.1, C50.2, C51.1, C54.1, C55.2, C56.2, C57.2, C58.2, C59.1, C60.1, C61.2, C62.2, C63.2, C64.2, C66.2, D11.1 (K), D13.2 (A), D16.1 (K), IC1.40 (GROUND), IC2.29 (GND), IC3.8 (GND), IC3.15 (E), IC4.8 (GND), IC4.15 (E), IC5.14 (GND), IC6.16 (Vss), IC7.16 (Vss), IC8.16 (Vss), IC9.16 (Vss), IC10.16 (Vss), IC11.16 (Vss), IC12.16 (Vss), IC13.16 (Vss), IC14.5 (GROUND), IC15.1 (Vbb), IC15.16 (Vss), IC16.1 (Vbb), IC16.16 (Vss), IC17.1 (Vbb), IC17.16 (Vss), IC18.1 (Vbb), IC18.16 (Vss), IC19.1 (Vbb), IC19.16 (Vss), IC20.1 (Vbb), IC20.16 (Vss), IC21.1 (Vbb), IC21.16 (Vss), IC22.1 (Vbb), IC22.16 (Vss), IC23.7 (GND), IC24.7 (GND), IC25.8 (GND), IC25.15 (Strobe), IC26.8 (GND), IC26.15 (Strobe), J1.1, J2.1, J3.B6 (GND), J3.B7 (GND), J3.B14 (GND), J4.2, LNK1.3 (LOW), LS1.1, R37.1, R40.1, R43.2, R46.2, R47.1, R50.2, R52.2, R53.2, R54.2, R56.1, R58.2, R63.1, TC1.1, TC1.3, TC2.1, TC2.3, TR3.3 (E), TR4.3 (E), U1.3 (GND), U2.2 (GND), X2.3
unnamed: C31.1, R35.1
unnamed: C31.2, J1.2
unnamed: C32.1, R36.1
unnamed: C38.1, C39.2, R46.1
unnamed: C38.2, R45.2, X2.2
unnamed: C43.2, R60.2, R61.2
unnamed: C63.1, IC23.9, R71.1
unnamed: C64.1, IC23.5, R70.1
unnamed: D1.2 (A), KB2.6
unnamed: D2.2 (A), KB2.3
unnamed: D3.2 (A), KB2.2
unnamed: D4.2 (A), KB2.1
unnamed: D5.2 (A), KB2.4
unnamed: D6.2 (A), KB2.5
unnamed: D7.2 (A), KB2.7
unnamed: D8.2 (A), KB2.8
unnamed: D9.1 (K), D10.2 (A)
unnamed: D10.1 (K), LS1.2
unnamed: C46.2, D11.2 (A), R55.1
unnamed: D12.1 (K), D16.2 (A), R55.2
unnamed: C32.2, C35.2, D9.2 (A), D13.1 (K), IC1.28 (MIC/TAPE), R35.2
unnamed: IC1.5 (A0), IC6.7 (A1), IC7.7 (A1), IC8.7 (A1), IC9.7 (A1), IC10.7 (A1), IC11.7 (A1), IC12.7 (A1), IC13.7 (A1), R17.1
unnamed: IC1.6 (A1), IC6.11 (A4), IC7.11 (A4), IC8.11 (A4), IC9.11 (A4), IC10.11 (A4), IC11.11 (A4), IC12.11 (A4), IC13.11 (A4), R18.1
unnamed: IC1.7 (A2), IC6.5 (A0), IC7.5 (A0), IC8.5 (A0), IC9.5 (A0), IC10.5 (A0), IC11.5 (A0), IC12.5 (A0), IC13.5 (A0), R19.1
unnamed: IC1.8 (A3), IC6.13 (A6), IC7.13 (A6), IC8.13 (A6), IC9.13 (A6), IC10.13 (A6), IC11.13 (A6), IC12.13 (A6), IC13.13 (A6), R20.1
unnamed: IC1.9 (A4), IC6.12 (A3), IC7.12 (A3), IC8.12 (A3), IC9.12 (A3), IC10.12 (A3), IC11.12 (A3), IC12.12 (A3), IC13.12 (A3), R21.1
unnamed: IC1.10 (A5), IC6.10 (A5), IC7.10 (A5), IC8.10 (A5), IC9.10 (A5), IC10.10 (A5), IC11.10 (A5), IC12.10 (A5), IC13.10 (A5), R22.1
unnamed: IC1.11 (A6), IC6.6 (A2), IC7.6 (A2), IC8.6 (A2), IC9.6 (A2), IC10.6 (A2), IC11.6 (A2), IC12.6 (A2), IC13.6 (A2), R23.1
unnamed: IC1.18 (D0), IC6.2 (Din), IC6.14 (Dout), R1.1
unnamed: IC1.21 (D1), IC7.2 (Din), IC7.14 (Dout), R2.1
unnamed: IC1.22 (D2), IC8.2 (Din), IC8.14 (Dout), R3.1
unnamed: IC1.25 (D3), IC9.2 (Din), IC9.14 (Dout), R4.1
unnamed: IC1.27 (D4), IC10.2 (Din), IC10.14 (Dout), R5.1
unnamed: IC1.29 (D5), IC11.2 (Din), IC11.14 (Dout), R6.1
unnamed: IC1.30 (D6), IC12.2 (Din), IC12.14 (Dout), R7.1
unnamed: IC1.31 (D7), IC13.2 (Din), IC13.14 (Dout), R8.1
unnamed: IC1.19 (KB0), KB1.5, R69.2
unnamed: IC1.20 (KB1), KB1.4, R68.2
unnamed: IC1.23 (KB2), KB1.3, R67.2
unnamed: IC1.24 (KB3), KB1.2, R66.2
unnamed: IC1.26 (KB4), KB1.1, R65.2
unnamed: IC1.39 (OSC), X1.1
unnamed: IC1.15 (U), R56.2, VR1.1, VidU1.1
unnamed: IC1.16 (V), R63.2, VR2.3, VidV1.2
unnamed: C30.1, IC1.13 (Vcc2), R34.2
unnamed: IC1.1 (~CAS), IC6.15 (~CAS), IC7.15 (~CAS), IC8.15 (~CAS), IC9.15 (~CAS), IC10.15 (~CAS), IC11.15 (~CAS), IC12.15 (~CAS), IC13.15 (~CAS)
unnamed: IC1.4 (~DRAMWE), IC6.3 (~WRITE), IC7.3 (~WRITE), IC8.3 (~WRITE), IC9.3 (~WRITE), IC10.3 (~WRITE), IC11.3 (~WRITE), IC12.3 (~WRITE), IC13.3 (~WRITE)
unnamed: IC1.12 (~INT), R26.1
unnamed: IC1.35 (~RAS), IC6.4 (~RAS), IC7.4 (~RAS), IC8.4 (~RAS), IC9.4 (~RAS), IC10.4 (~RAS), IC11.4 (~RAS), IC12.4 (~RAS), IC13.4 (~RAS), R32.1, R57.1
unnamed: IC1.34 (~ROMCS), R33.1
unnamed: IC1.17 (~Y), R47.2, R48.1, VidY1.2
unnamed: IC2.6 (~CPUCLK), R25.1, TR3.1 (C)
unnamed: IC3.4 (1Y), R22.2
unnamed: IC3.7 (2Y), R21.2
unnamed: IC3.9 (3Y), R20.2
unnamed: IC3.12 (4Y), R23.2
unnamed: IC3.1 (S), IC4.1 (S), R32.2
unnamed: IC4.4 (1Y), R18.2
unnamed: IC4.7 (2Y), R17.2
unnamed: IC4.12 (4Y), R19.2
unnamed: IC5.27 (OE1), LNK2.4
unnamed: IC5.20 (~CE), LNK2.1
unnamed: C52.2, IC14.4 (B-Y), R38.2, VR1.2
unnamed: C36.2, IC14.3 (CHROMA_BIAS), R40.2, R41.2
unnamed: C37.1, IC14.18 (CHROMA_LAG), R45.1
unnamed: C39.1, IC14.1 (CHROMA_LEAD)
unnamed: IC14.17 (CHROMA_OSC_OUTPUT), R43.1, R44.1
unnamed: C65.1, IC14.13 (CHROMA_SUB_CARRIER), R72.2
unnamed: C53.2, IC14.2 (R-Y), R39.2, VR2.2
unnamed: IC14.12 (VIDEO_INPUT), R42.2
unnamed: IC15.5 (A0), IC16.5 (A0), IC17.5 (A0), IC18.5 (A0), IC19.5 (A0), IC20.5 (A0), IC21.5 (A0), IC22.5 (A0), IC26.7 (2Y)
unnamed: IC15.7 (A1), IC16.7 (A1), IC17.7 (A1), IC18.7 (A1), IC19.7 (A1), IC20.7 (A1), IC21.7 (A1), IC22.7 (A1), IC26.12 (4Y)
unnamed: IC15.6 (A2), IC16.6 (A2), IC17.6 (A2), IC18.6 (A2), IC19.6 (A2), IC20.6 (A2), IC21.6 (A2), IC22.6 (A2), IC26.4 (1Y)
unnamed: IC15.12 (A3), IC16.12 (A3), IC17.12 (A3), IC18.12 (A3), IC19.12 (A3), IC20.12 (A3), IC21.12 (A3), IC22.12 (A3), IC25.9 (3Y)
unnamed: IC15.11 (A4), IC16.11 (A4), IC17.11 (A4), IC18.11 (A4), IC19.11 (A4), IC20.11 (A4), IC21.11 (A4), IC22.11 (A4), IC25.7 (2Y)
unnamed: IC15.10 (A5), IC16.10 (A5), IC17.10 (A5), IC18.10 (A5), IC19.10 (A5), IC20.10 (A5), IC21.10 (A5), IC22.10 (A5), IC25.4 (1Y)
unnamed: IC15.13 (A6), IC16.13 (A6), IC17.13 (A6), IC18.13 (A6), IC19.13 (A6), IC20.13 (A6), IC21.13 (A6), IC22.13 (A6), IC25.12 (4Y)
unnamed: IC15.9 (AR), IC16.9 (AR), IC17.9 (AR), IC18.9 (AR), IC19.9 (AR), IC20.9 (AR), IC21.9 (AR), IC22.9 (AR), IC26.9 (3Y)
unnamed: IC15.15 (~CAS), IC16.15 (~CAS), IC17.15 (~CAS), IC18.15 (~CAS), IC19.15 (~CAS), IC20.15 (~CAS), IC21.15 (~CAS), IC22.15 (~CAS), IC23.6
unnamed: IC15.4 (~RAS), IC16.4 (~RAS), IC17.4 (~RAS), IC18.4 (~RAS), IC19.4 (~RAS), IC20.4 (~RAS), IC21.4 (~RAS), IC22.4 (~RAS), IC23.3, IC23.4, R71.2
unnamed: IC15.3 (~WRITE), IC16.3 (~WRITE), IC17.3 (~WRITE), IC18.3 (~WRITE), IC19.3 (~WRITE), IC20.3 (~WRITE), IC21.3 (~WRITE), IC22.3 (~WRITE), IC23.11, IC24.5
unnamed: IC23.10, IC24.8
unnamed: IC24.6, IC24.9
unnamed: IC23.8, IC25.1 (SelectAB), IC26.1 (SelectAB), R70.2
unnamed: IC26.10 (3B), LNK1.2 (SELECT)
unnamed: J2.2, R36.2, R37.2
unnamed: R44.2, TC2.2, X2.1
unnamed: R61.1, T1.1 (AA)
unnamed: T1.2 (AB), TR4.2 (B)
unnamed: TC1.2, X1.2
unnamed: R48.2, R49.2, R50.1, TR1.2 (B)
unnamed: C65.2, R51.1, TR1.1 (C), TR2.2 (B)
unnamed: R52.1, TR1.3 (E)
unnamed: C25.1, C40.1, C42.2, R49.1, R51.2, R64.1, R72.1, TR2.1 (C), U1.1 (+5V)
unnamed: R53.1, TR2.3 (E), U1.2 (INPUT), Vid1.2
unnamed: C67.1, R24.1, TR3.2 (B)
unnamed: C74.2, R58.1, R59.1, TR5.2 (B)
unnamed: R60.1, TR5.1 (C)
U: J3.B18 (U), VidU1.2
V: J3.B17 (V), VidV1.1
VIDEO: J3.B15 (VIDEO), Vid1.1
~BUSACK: IC2.23 (~BUSACK), J3.B26 (BUSACK)
~BUSRQ: IC2.25 (~BUSRQ), J3.B19 (BUSRQ), R30.1
~CLK: C67.2, IC1.32 (Ø~CPU), J3.B8 (CLOCK), R24.2, R73.1
~HALT: IC2.18 (~HALT), J3.A15 (HALT)
~INT: IC2.16 (~INT), J3.A13 (INT), R26.2
~IOREQULA: C51.2, IC1.33 (~IOREQ), J3.B13 (IORQGE), R27.1, TR6.3 (E)
~IORQ: IC2.20 (~IORQ), J3.A17 (IOREQ), R27.2
~M1: IC2.27 (~M1), J3.A24 (M1)
~MREQ: IC1.38 (~MREQ), IC2.19 (~MREQ), IC23.1, IC23.2, J3.A16 (MREQ), LNK2.2
~NMI: IC2.17 (~NMI), J3.A14 (NMI), R28.1
~RD: IC1.3 (~RD), IC2.21 (~RD), IC5.22 (~OE), IC24.4, J3.A18 (RD)
~RESET: C27.1, IC2.26 (~RESET), J3.B20 (RESET), R31.1
~RFSH: C54.2, IC2.28 (~RFSH), J3.A25 (RFSH), R57.2
~ROMCS: J3.B25 (ROMCS), LNK2.3, R33.2
~WAIT: IC2.24 (~WAIT), J3.A21 (WAIT), R29.1
~WR: IC1.2 (~WR), IC2.22 (~WR), IC23.12, IC23.13, J3.A19 (WR)
~Y: J3.B16 (Y), VidY1.1

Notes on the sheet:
OPTIONAL 32K RAM UPGRADE
32K RAM TYPE SELECT - TI ONLY

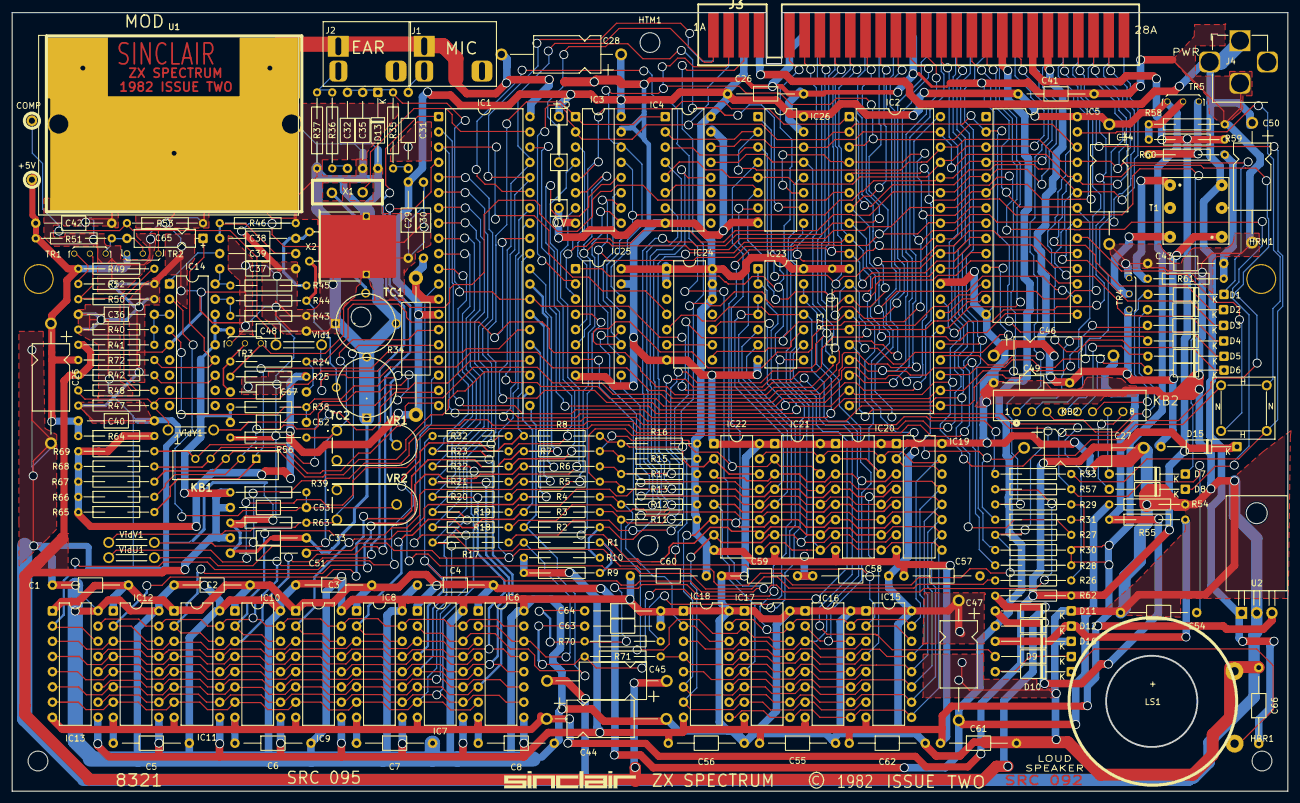
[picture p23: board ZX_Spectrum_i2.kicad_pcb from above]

Board: 2 copper layers, 213.1 x 130.0 mm, 199 parts (0 on the bottom side), 149 nets.

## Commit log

2026-08-13 Update README with project details and modifications
    Expanded README to provide detailed information about the Kicad project for the ZX Spectrum 48K Issue 2, including modifications and component requirements.
2026-08-13 Improve README.md for clarity and detail
    Updated text for clarity and added details about PCB layout creation.
2026-08-13 Add files via upload
    Initial upload
    [ZX_Spectrum_i2-B_Cu.gbr, ZX_Spectrum_i2-B_Silkscreen.gbr, ZX_Spectrum_i2-Edge_Cuts.gbr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]
2026-09-27 Add files via upload
    Updated board sizes and hole positions along with new step models.
    [ZX_Spectrum_i2-B_Cu.gbr, ZX_Spectrum_i2-B_Silkscreen.gbr, ZX_Spectrum_i2-Edge_Cuts.gbr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]
2026-09-27 Add files via upload
    Added stp files
    [RF MOD Astec UM1233 E36.step]
2026-09-27 Add files via upload
    Added more stp files.
    [Z80 - SGS.step]

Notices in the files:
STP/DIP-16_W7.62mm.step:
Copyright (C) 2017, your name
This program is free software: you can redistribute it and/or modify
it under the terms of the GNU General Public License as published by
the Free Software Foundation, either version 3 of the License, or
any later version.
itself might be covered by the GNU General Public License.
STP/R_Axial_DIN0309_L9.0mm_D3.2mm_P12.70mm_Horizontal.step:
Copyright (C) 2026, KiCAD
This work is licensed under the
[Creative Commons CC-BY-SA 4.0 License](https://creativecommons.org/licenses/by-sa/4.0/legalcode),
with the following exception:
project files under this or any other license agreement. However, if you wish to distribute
